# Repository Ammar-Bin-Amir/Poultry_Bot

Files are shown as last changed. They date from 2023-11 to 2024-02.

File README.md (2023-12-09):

# Poultry Bot

Poultry Bot is a major technological breakthrough for the poultry industry as it provides solution for utmost problems faced in a poultry farm. The purpose of poultry bot is to completely revolutionize the century old farming practices used till now by introducing the latest technology for 1,190 billion rupees turnover generating sector. The goal is to minimize the biosecurity risk to help improve the production. Further, assisting human to make more informed and better decisions. Poultry bot is an autonomous self-driven robot, monitoring several factors effecting on a poultry farm by implementing ROS and IoT along with LIDAR mapping.

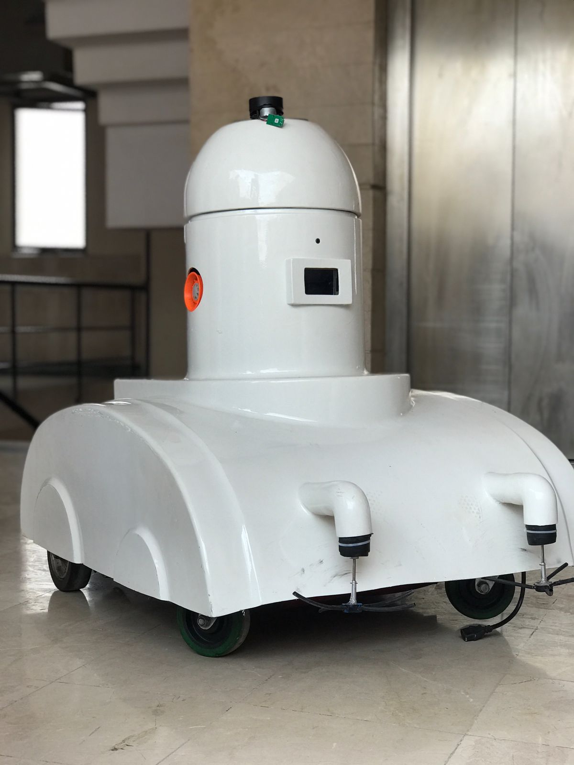
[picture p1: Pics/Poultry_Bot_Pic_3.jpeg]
Snapshot of Poultry Bot


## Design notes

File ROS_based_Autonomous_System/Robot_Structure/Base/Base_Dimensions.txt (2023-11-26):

4.5' Length
2.5' Width
2' Height
6" Ground Clearance
4.5" Length of Rod for Wheel Attachment
3.5" Location of Hole in Rod for Wheel Attachment

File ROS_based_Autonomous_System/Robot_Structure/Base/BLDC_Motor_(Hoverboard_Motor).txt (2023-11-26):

BLDC Motor (Hoverboard Motor)
*******************************
https://www.parallax.com/product/6-5-hub-motor-with-encoder/

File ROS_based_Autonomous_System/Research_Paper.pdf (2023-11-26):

1

# Poultry Bot: Autonomous Movement

Syed Sohaib Shere, Zain Ali, Muhammad Farhan Ur Rehman Malik, and Syed Musab Ullah Hussaini

Abstract—Poultry Bot is a major technological breakthrough
for the poultry industry as it provides solution for utmost problems faced in a poultry farm. The purpose of poultry bot is to completely revolutionize the century old farming practices used till now by introducing the latest technology for 1,190 billion rupees turnover generating sector. [1] The goal is to minimize the biosecurity risk to help improve the production. Further, assisting human to make more informed and better decisions. Poultry bot is an autonomous self-driven robot, monitoring several factors effecting on a poultry farm by implementing ROS and IoT along with LIDAR mapping.

Index Terms—Major Technical Breakthrough, ROS based Autonomous Self-Driven Robot, IoT Monitoring, LIDAR Mapping

I. INTRODUCTION

Poultry as a farming activity already existed for ages, over the 20th century, it became a real profession. In that century, poultry farming underwent several major revolutions in which the production system was drastically changed. In today’s poultry farming a significant part of the daily animal care is mechanized or automated like manure removal, climate control, automated medication, and litter racking. As these tasks contained limited complexity and variation, that are fulfilled using stepper motors and simple control logic. The properly running poultry shed still requires good stockman ship with intensive monitoring and awareness of animal of behavior and interactions as well as proper management and conscientiously performing of the daily task. This poultry bot comprises of implementation of IoT for monitoring important factors such as temperature, humidity, and air quality that can easily be detected by electronic discrete sensors that are particularly developed for single dedicated task. Another, innovative feature that is integrated with this robot is its autonomous movement which is to be done using a minicomputer which is specifically used to make this bot unique, efficient, and remarkable. Along with this, the technology of LIDAR is adopted to make the bot move precisely in the field area. Pesticide, that cannot be ignored when it comes to poultry care, is also integrated that will follow the defined scheduled spraying with controlled concentration according to the requirements of the shed.

II. PROBLEM STATEMENT

There are almost 15000 poultry farms in Pakistan despite of having such a huge industry not a single poultry robot is present due to restrictions on self-import, uneconomical cost, and lack of after sales services. [1]

By notifying real-time alerts and being cost-effective by lowering operational costs. Poultry Bot will enable the farmer to enhance productivity while eliminating the need for physical vigilance. The goal of poultry bot is to fully automate the process of monitoring and maintaining a poultry farm by providing tech-based solution for daily faced problems.

III. LITERATURE REVIEW

As for the poultry robots available worldwide, different robots are introduced with capabilities of various problem solving. Some of the available poultry robots are discussed as follows:

A. Poultry Patrol
By using thermal imaging, it enables the robot to detect disease and fatalities. The movement of birds is monitored to analyze their health. [2]
B. Octopus Robots
The bots continuously measure environmental factors, such as temperatures, humidity, carbon dioxide and ammonia levels, alerting farmers in real-time of deviations and potential problems. [3]
C. Robot Egg Collector
Poultry farms that give chickens open space to move around face the problem of random eggs laying all over the farm. The robotic egg collectors use an array of sensors to find and collect eggs without disturbing the chickens. [4]
D. Poultry Safe
It is capable of dealing with all types of substrates, turning and ventilating litter to prevent the exertion of ammonia gas and other diseases. [5]

IV. AIMS AND OBJECTIVES

The aims and objectives of this project is:

- To optimize the working time.
- To improve animal welfare.
- To increase the ADGs (average daily gain).
- To increase food security.
- To improve litter racking quality.
- To minimize the workforce.
- To reduce the human interaction.
- To make the project cost efficient.

2

V. FEATURES

The following features are included in this project:

1) LIDAR
a) Mapping
b) Localization
c) Navigation
2) Driving System
a) Remote Control
b) Autonomous Movement
3) Power Supply Unit
4) Litter Raking

VI. INDUSTRIAL APPLICATIONS

Poultry bot allows a poultry farm to improve the quality of poultry by improving animal well-being. This poultry bot will match the parallelism with the industrial revolutionary era 4.0 which is IoT based implementation in the industrial field. In addition to that, robotics technology in the form of ROS has been used that made the poultry bot move autonomously inside the poultry farm which will increase the efficiency and productivity. A major issue of lack in supervision of the animals that includes pest control, human concentration and inaccurate environmental factors monitoring would be countered by this single poultry bot that will boost the monthly revenue. Last but not the least, this bot would be cost efficient as it will minimize the monthly expenditures.

VII. HARDWARE DETAILS

The hardware details are as follows:

1) Mini PC
2) Arduino Mega 2560
3) BMS HX-3S-FL25A-A
4) 12V 1000W Inverter
5) Buck Converter XL-4016
6) Battery Pack Li-Ion 3S4P
7) Bluetooth Module HC-05
8) Two Channel Relay Module
9) Incremental Rotary Encoder
10) Battery Level Indicator MH-DL 18S
11) IBT2 H-Bridge Motor Driver Module
12) DC Geared Motors DGO-7024SIA
13) DC 12V 100W 775 High Speed Long Shaft Motor
14) RP Lidar A1M8 360 Degree Laser Scanner Development Kit

VIII. SOFTWARE DETAILS

The software details are as follows:

1) RViz
2) Linux
3) Gazebo
4) AutoCAD
5) Adobe Illustrator
6) Arduino Software
7) ROS (Robot Operating System)

IX. TENTATIVE OUTPUT

A poultry bot performs an inspection on the chicks in the shed, from litter racking to temperature monitoring, to assist the farmer in caring for their flock. Implementing this technology, will improve the quality of poultry and aid in achieving better results. The self-driving and self-controlling robot will reduce reliance on humans, resulting in increased production.

X. FUTURE WORK
- This project can be further improved by embracing AI and data-driven systems and enhancing disease control measures.
- Embrace AI and Data-Driven Systems: Emphasize the integration of highly adaptive artificial intelligence and data-driven systems in broiler and breeder production. These technologies can optimize operations, improve decision-making, and enhance overall efficiency.
- Enhance Disease Control Measures: Develop advanced disease detection and prevention strategies using AIdriven systems. Implement real-time monitoring and early warning systems to identify and control.

XI. REFERENCES

[1] “AN OVERVIEW OF PAKISTAN POULTRY INDUSTRY YEAR 2020-2021 – Pakistan Poultry Association.” https://pakistanpoultryassociation.com.pk/news/an-overview-of-pakistanpoultryindustry-year-2019-2020/ (accessed Jun. 20, 2022).
[2] “Autonomous robotics for the poultry shed | The Poultry Site.”
https://www.thepoultrysite.com/articles/autonomous-robotics-for-the-poultryshed (accessed Jun. 20, 2022).
[3] “Robots: the new frontier in poultry production | The Poultry Site.”
https://www.thepoultrysite.com/articles/robots-the-new-frontier-in-poultryproduction (accessed Jun. 20, 2022).
[4] “Best New Poultry Farm Equipment – 7 Robot & Automation Products.” https://agsolarsolutions.com/best-new-poultry-farm-equipment-2019/ (accessed Jun. 20, 2022).
[5] “Poultry Technology: Rise of the robots - Canadian Poultry MagazineCanadian Poultry Magazine.” https://www.canadianpoultrymag.com/rise-of-the-robots-30876/ (accessed Jun. 20, 2022).

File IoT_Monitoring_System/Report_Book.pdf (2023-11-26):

ST-13, Block 7, Gulshan-e-Iqbal, Abul Hasan Isphahani Road, Opposite Safari Park, P.O. Box 75300, Karachi, Pakistan. Phone: 34978274-5; 34994305; 34982476; http://www.uit.edu

# USMAN INSTITUTE OF TECHNOLOGY

### Affiliated with NED University of Engineering & Technology, Karachi

## Department of Electrical Engineering

## B.E. Electrical (Electronics Engineering)

## FINAL YEAR PROJECT REPORT

## Batch-2019

## POULTRY BOT: MONITORING SYSTEM

By

Ammar Bin Amir | 19B-004-EE
Maaz Siddiqui | 19B-008-EE
Osama Bin Khalid Raza | 17B-051-EE
Muhammad Qasim Umer Qureshi | 19B-062-CE

Supervised by

### Dr. Abid Karim (Professor)

Poultry Bot: Monitoring System

I

DECLARATION

I hereby declare that this project report is based on my original work except

for citations and quotations which have been duly acknowledged. I also declare that

it has not been previously and concurrently submitted for any other degree or award

at USMAN INSTITUTE OF TECHNOLOGY or other institutions.

Student Name (Student ID): Ammar Bin Amir (19B-004-EE)

Signature: _________________________

Student Name (Student ID): Maaz Siddiqui (19B-008-EE)

Signature: _________________________

Student Name (Student ID): Osama Bin Khalid Raza (17B-051-EE)

Signature: _________________________

Student Name (Student ID): Muhammad Qasim Umer Qureshi (19B-062-CE)

Signature: _________________________

Date: _________________________

II

ACKNOWLEDGEMENT

Alhamdulillah, praise to Allah the almighty for His blessings and for

allowing us to complete this study and completion of the Poultry Bot project in the

given time to whom we would like to express our highest gratitude.

Then, we would like to thank my Final Year Project Supervisor, Dr. Abid

Karim, for his continuous support and guidance. He had not only given essential

theories and ideas for completing this project but also informally guided us in

developing our values to make us better people.

The sponsorship provided by the alumnus of UIT, Engr. Athar Alam has

enabled us to access essential resources, materials, and equipment necessary for the

successful execution of our project. His belief in the potential of our endeavor has

motivated us throughout this journey, and we are immensely grateful for his trust in

our abilities.

We would also like to express our great appreciation to our Sponsor and

donor of Mohammad Younus Khan Award of Rs.50,000 (rupees fifty thousand only)

for final year projects (FYPs) groups working in the area of Electric Vehicles (EVs).

Our earnest appreciation to Engr. Muhammad Timur for all his guidance and

assistance in helping us throughout the time of the project period. His guidance and

expert insights have been crucial in shaping the direction of our project. His

experience has provided us with valuable perspectives, helping us to refine our ideas

and develop innovative solutions.

Finally, an honorable mention goes to our families, especially our parents,

who have always prayed for our success and given their utmost moral support in our

life. We hope we can always be there for them in the way they supported us.

III

POULTRY BOT: MONITORING SYSTEM

ABSTRACT

Poultry Bot is a major technological breakthrough for the poultry industry as

it provides solutions for the utmost problems faced in a poultry farm. The purpose of

the poultry bot is to completely revolutionize the century-old farming practices used

till now by introducing the latest technology for the 1,190 billion rupees turnover

generating sector. The goal is to minimize the biosecurity risk to help improve

production. Furthermore, assisting humans to make more informed and better

decisions. The poultry bot is an autonomous self-driven robot that performs all the

required operations in the poultry farm which includes monitoring, patrolling, litter-

racking, and disinfectant spraying. Overall, the Poultry Bot's introduction to the

poultry industry heralds a transformative era, promising higher levels of biosecurity,

production enhancement, and informed decision-making.

IV

TABLE OF CONTENTS

DECLARATION | I
ACKNOWLEDGEMENT | II
ABSTRACT | III
TABLE OF CONTENTS | IV
LIST OF FIGURES | VII
LIST OF TABLES | VIII
PROGRAM LEARNING OUTCOMES (PLOS) MAPPING | IX

V

VI

VII

LIST OF FIGURES

FIGURE 2.22 ARDUINO IDE (INTEGRATED DEVELOPMENT ENVIRONMENT) SOFTWARE

FIGURE 3.2 COMPLETE CIRCUIT OF PROCESSING UNIT INTEGRATED ON THE

FIGURE 3.3 INDICATION OF POWER SUPPLY UNIT CONTROLLED THROUGH SWITCH ALONG WITH BATTERY LEVEL INDICATOR INDICATING 75% CHARGING

FIGURE 4.1 IMAGE OF ROBOT STRUCTURE DISPLAYING NEXTION HMI LCD, CAMERA MODULE, AND TWO SPRAY NOZZLES (IN ORANGE COLOR) ON LEFT AND RIGHT 49 FIGURE 4.2 IMAGE OF NEXTION HMI LCD (BOTTOM) AND CAMERA MODULE (TOP)

VIII

LIST OF TABLES

IX

PROGRAM LEARNING OUTCOMES (PLOs) MAPPING

Chapters 1 through 4 and Appendix

PLO-(x)-Communication

PLO-(viii)-Ethics

PLO-(ix)-Individual & Teamwork

Chapter 01-Introduction | PLO-(ii)-Problem Analysis
Chapter 02-Methodology | PLO-(iv)-Investigation

Chapter 03-Implementation

PLO-(iii)-Design/Development of Solution

PLO-(v)-Modern Tool Usage

# CHAPTER # 01

# INTRODUCTION

## 1. Introduction

Poultry as a farming activity already existed for ages, over the 20th century, it

became a real profession. In that century, poultry farming underwent several major

revolutions in which the production system was drastically changed. In today’s

poultry farming a significant part of the daily animal care is mechanized or

automated like manure removal, climate control, automated medication, and litter

raking. As these tasks contain limited complexity and variation, they are fulfilled

using motors and simple control logic. The properly running poultry shed still

requires good stockmanship with intensive monitoring and awareness of animal

behavior and interactions as well as proper management and conscientious

performing of the daily task. This poultry bot comprises of implementation of IoT for

monitoring important factors such as temperature, humidity, and air quality that can

easily be detected by electronic discrete sensors that are particularly developed for a

single dedicated task. Another, innovative feature that is integrated with this robot is

its autonomous movement which is to be done using a minicomputer which is

specifically used to make this bot unique, efficient, and remarkable along with the

technology of LIDAR which is adopted to make the bot move precisely in the field

area. Disinfectant and anti-bacterial, which cannot be ignored when it comes to

poultry care, are also integrated that will follow the user-defined scheduled spraying

with controlled concentration according to the requirements of the shed.

### 1.1. Problem Statement

The poultry industry faces various challenges related to efficiency,

productivity, and animal welfare. However, the major challenge facing poultry

farming is reconciled productivity, biosecurity, and expectations of society where the environment and animal welfare are of major concern. To address

these challenges, the development of a poultry robot is proposed. The objective

of the poultry robot is to automate and optimize various tasks involved in

poultry farming and management.

There are almost 15000 poultry farms in Pakistan despite having such a

huge industry not a single poultry robot is present due to restrictions on self-

import, uneconomical cost, and lack of after-sales services[1]
. Poultry Bot will

enable the farmer to enhance productivity while eliminating the need for

physical vigilance. The goal of the poultry bot is to fully automate the process

of monitoring and maintaining a poultry farm by providing tech-based

solutions for daily faced problems.

By deploying poultry robots, farmers can significantly reduce the labor

costs associated with poultry farming while maintaining high standards of

animal welfare. The robot's ability to work continuously ensures round-the-

clock monitoring and care for the birds, leading to better overall farm

management. Moreover, the data collected by the robot's sensors can be

analyzed to gain valuable insights into the birds' health, behavior patterns, and

productivity, enabling farmers to make data-driven decisions and optimize

their operations further.

### 1.2. Literature Review

As for the poultry robots available worldwide, different robots are

introduced with capabilities of various problem-solving. Some of the available

poultry robots are discussed as follows:

### 1.2.1. Poultry Patrol

By using thermal imaging, it enables the robot to detect disease

and fatalities. The movement of birds is monitored to analyze their

health[2]

Figure 1.1 Poultry Patrol

### 1.2.2. Octopus Robot

The bots continuously measure environmental factors, such as

temperatures, humidity, carbon dioxide, and ammonia levels, alerting

farmers in real time of deviations and potential problems[3]

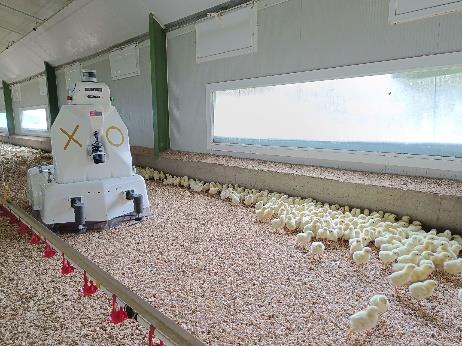
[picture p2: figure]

Figure 1.2 Octopus Robot

### 1.2.3. Robot Egg Collector

Poultry farms that give chickens open space to move around face

the problem of random eggs laying all over the farm. The robotic egg

collectors use an array of sensors to find and collect eggs without

disturbing the chickens[4]

Figure 1.3 Robot Egg Collector

### 1.2.4. Poultry Safe

It is capable of dealing with all types of substrates, turning and

ventilating litter to prevent the exertion of ammonia gas and other

diseases.

All the robots mentioned above are catering to a certain problem

but there are certain limitations and challenges associated with poultry

robots, including technological constraints, cost considerations, and

integration with existing farm systems. However, poultry bot minimizes

these problems[5]

Figure 1.4 Poultry Safe

### 1.3. Aims and Objectives

The Poultry Bot aims to enhance daily poultry farm production

conditions with advanced technologies focused on health, biosecurity, and

productivity. Objectives include improving poultry quality by enhancing animal well-being and minimizing antibiotic use, sanitizing bedding to control

multi-resistant bacteria and infectious diseases while reducing ammonia levels,

and uniformly decontaminating buildings during fallow periods. Additionally,

the Poultry Bot aims to increase yields through improved animal weight and

reduced interim costs, promoting more efficient and sustainable poultry

farming practices.

### 1.3.1. To Optimize the Working Time

The Poultry Bot aims to streamline and optimize the working

time in poultry farming operations by employing its autonomous and

connected features. The robot can efficiently perform tasks that would

otherwise require significant manual labor and time. The Poultry Bot can

complete essential functions such as decontamination, sanitization, and

monitoring without the need for constant human supervision. This

optimization of working time allows poultry farmers to focus on other

critical aspects of their operations, leading to increased productivity and

improved overall efficiency.

### 1.3.2. To Improve Animal Welfare

The robot's atomization technology allows the decontamination

and sanitization of the poultry farm environment, creating a healthier and

cleaner living space for the birds. By minimizing the presence of harmful

bacteria, infectious agents, and ammonia concentrations in the bedding,

the Poultry Bot promotes better health and comfort for the birds.

### 1.3.3. To Increase the ADGs (Average Daily Gain)

The Poultry Bot plays a crucial role in boosting the average daily

gain (ADG) of poultry. By maintaining a clean and hygienic

environment, the robot reduces stress factors that can hinder the growth

and development of the birds. The optimized living conditions provided

by the Poultry Bot contribute to improved feed conversion rates and

nutrient absorption, leading to higher ADGs.

### 1.3.4. To Improve Litter Raking Quality

The Poultry Bot's technology for regularly cleaning and removing

soiled litter ensures a high-quality decontamination process, including

the sanitization of the bedding. By effectively reducing the concentration

of multi-resistant bacteria and ammonia, the robot helps maintain cleaner

and healthier litter-raking conditions. Improved litter quality not only

benefits animal health and welfare but also facilitates easier waste

management for poultry farmers, leading to more sustainable and eco-

friendly practices.

### 1.3.5. To Minimize the Workforce

With its autonomous and connected features, the Poultry Bot

minimizes the need for a large workforce in poultry farming operations.

Once deployed, the robot can carry out its tasks independently, reducing

the labor-intensive aspects of manual cleaning and decontamination. This

cost-effective solution allows farmers to optimize labor resources,

allocate manpower to more strategic tasks, and potentially reduce

operational expenses.

# CHAPTER # 02

# METHODOLOGY

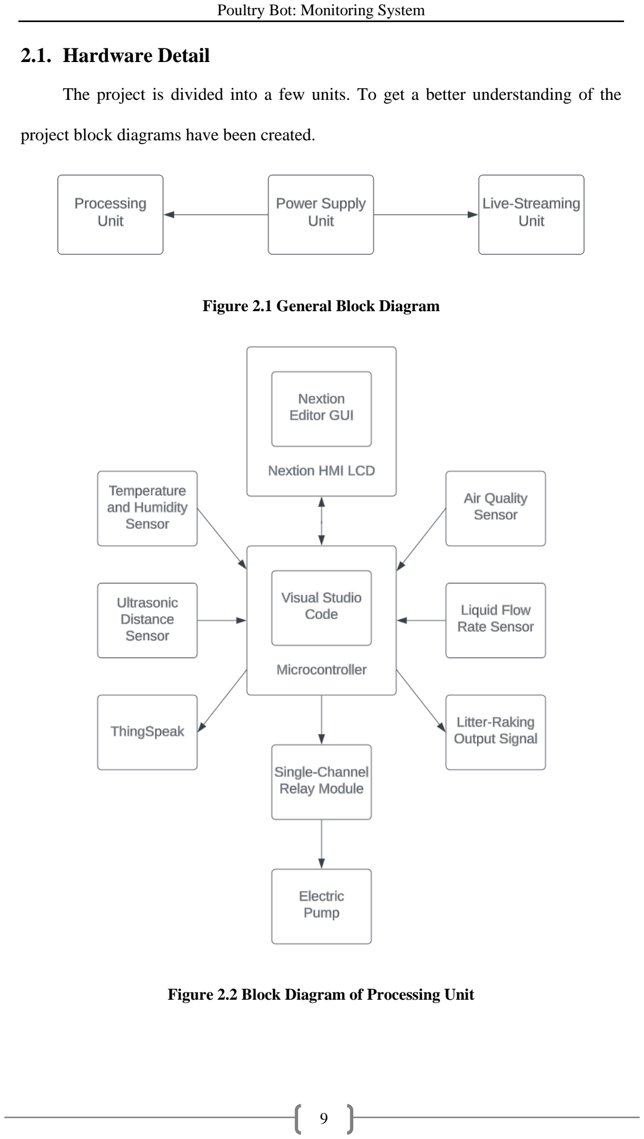
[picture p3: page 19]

### 2.1. Hardware Detail

The project is divided into a few units. To get a better understanding of the

project block diagrams have been created.

Figure 2.1 General Block Diagram

Figure 2.2 Block Diagram of Processing Unit

Figure 2.3 Block Diagram of Power Supply Unit

Figure 2.4 Block Diagram of Live-Streaming Unit

The hardware used in this project is mentioned in detail as follows:

### 2.1.1. Microntroller

A microcontroller is a compact integrated circuit that contains a

processor core, memory, and peripherals, designed for embedded systems and

control applications. It serves as the brain of small-scale devices, managing

their operations and executing tasks based on pre-programmed instructions.

ESP32 DevKit Module is used as a microcontroller in this project.

The ESP32 DevKit module is a versatile and powerful development

board based on the ESP32 microcontroller. It features a dual-core 32-bit

processor running at up to 240 MHz, equipped with Wi-Fi and Bluetooth

connectivity, making it ideal for Internet of Things (IoT) projects. The module

offers a wide range of peripherals, including GPIO pins, UART, SPI, I2C,

ADC, and PWM, providing flexibility for various applications. With ample

memory resources and built-in security features, it enables the efficient

development of connected devices and applications. Its compact form factor,

cost-effectiveness, and extensive software support through the Espressif IoT

Development Framework (ESP-IDF) and Arduino IDE make the ESP32

DevKit a popular choice for IoT prototyping and development. The ESP32

DevKit module operates at a voltage range of typically 3.3V to 3.6V, making it

compatible with various power supply sources. In terms of current

specifications, the ESP32 DevKit module typically consumes around 80mA to

260mA during normal operation, depending on the tasks and functionalities

enabled.

Figure 2.5 Microcontroller: ESP32 Devkit Module

### 2.1.2. Temperature and Humidity Sensor

Temperature is a measure of the average kinetic energy of the particles

in a substance. It determines the hotness or coldness of an object and is

measured using the Celsius, Fahrenheit, or Kelvin scale.

Humidity is a measure of the amount of water vapor present in the air.

It indicates how saturated the air is with water vapor at a specific temperature.

The DHT22 is a digital temperature and humidity sensor designed to

accurately measure ambient temperature and relative humidity in a wide range

of applications. It features a single-wire communication interface, making it

easy to integrate with microcontrollers and other devices. The sensor boasts a

temperature measurement range of -40°C to 80°C with an accuracy of ±0.5°C and a humidity measurement range of 0% to 100% with an accuracy of ±2%.

Its low power consumption and quick response time make it suitable for

various projects such as weather monitoring systems, home automation, and

industrial applications where reliable temperature and humidity data are

essential. The DHT22 temperature and humidity sensor operates within a

voltage range of 3.3V to 5.5V, making it compatible with most

microcontrollers and embedded systems. When powered, the DHT22

consumes an average current of around 2.5mA during normal operation.

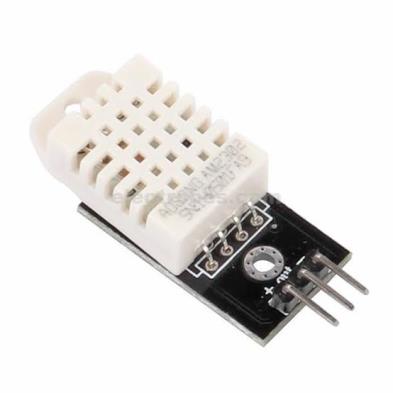
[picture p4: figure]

Figure 2.6 Temperature and Humidity Sensor: DHT22

### 2.1.3. Air Quality Sensor

Air quality refers to the cleanliness and healthiness of the air we

breathe, determined by the concentration of pollutants and particulate matter in

the atmosphere, which can impact human health and the environment. Factors

such as emissions from vehicles, industrial activities, and natural sources

contribute to air quality levels.

The MQ135 is a gas sensor module used to detect a wide range of

harmful gases in the atmosphere, including ammonia, nitrogen oxides,

benzene, and other volatile organic compounds. It operates on the principle of

chemiresistance, where the resistance of the sensing material changes when it comes into contact with specific gases, thus allowing the sensor to measure gas

concentrations. The MQ135 is commonly utilized in various applications, such

as air quality monitoring devices, indoor air quality assessments, and gas leak

detection systems, due to its sensitivity and cost-effectiveness, making it a

popular choice for environmental monitoring and safety purposes. It typically

operates at a voltage of 5V DC and consumes a low current, usually around

150mA, making it suitable for use with microcontrollers like Arduino and

ESP32.

Figure 2.7 Air Quality Sensor: MQ135

### 2.1.4. Ultrasonic Distance Sensor

Ultrasonic distance refers to measuring the distance to an object by

emitting high-frequency sound waves and calculating the time it takes for the

waves to bounce back after hitting the object.

The HC-SR04 is an ultrasonic sensor module widely used for distance

measurement in various applications. It operates by emitting ultrasonic sound

waves and measuring the time it takes for the waves to bounce back after

hitting an object. The module consists of two main components: a transmitter

and a receiver. The transmitter sends out ultrasonic pulses, and the receiver

detects the echoes. By calculating the time difference between sending and receiving signals and knowing the speed of sound in the air, the module can

determine the distance to the object. It typically has a measurement range of

2cm to 400cm and features four pins: VCC for power supply (5V), GND for

ground connection, TRIG for trigger signal input, and ECHO for echo signal

output. This simple yet effective design makes the HC-SR04 popular for

distance sensing in robotics, automation, and other projects. The HC-SR04

ultrasonic sensor operates at a voltage range of 5V DC, making it compatible

with most microcontrollers and Arduino boards. The sensor's operating current

typically ranges from 2mA to 15mA during active mode, depending on the

duration and frequency of measurements.

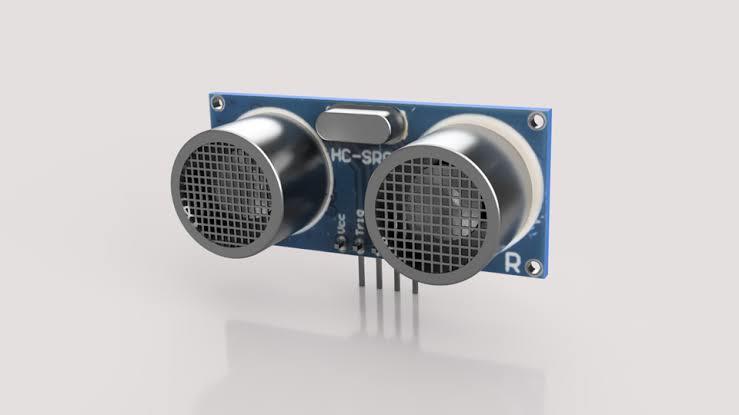
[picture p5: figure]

Figure 2.8 Ultrasonic Distance Sensor: HC-SR04

### 2.1.5. Liquid Flow Rate Sensor

Liquid flow rate refers to the volume of liquid passing through a point

per unit of time, typically measured in liters per minute or gallons per hour.

The YF-S201 is a liquid flow sensor module widely used in various

applications to measure the flow rate of liquids. Its specification includes a

compact design, featuring a small and lightweight body for easy integration

into different systems. The sensor utilizes a hall effect sensor to detect the flow

of liquids, making it highly reliable and accurate. It operates within a wide flow rate range, typically from 0.3 to 6 liters per minute, and is compatible

with various liquids, including water and other non-corrosive liquids. The YF-

S201 is equipped with a pulse output that provides a frequency signal

corresponding to the flow rate, making it convenient for interfacing with

microcontrollers and other electronic devices. The voltage specifications for

the YF-S201 typically range from 5V to 24V DC, making it compatible with

various microcontrollers and systems. The YF-S201 water flow sensor has a

low current consumption, typically in the range of a few milliamperes during

operation, having a maximum working current of up to 15mA.

Figure 2.9 Liquid Flow Rate Sensor: YF-S201

### 2.1.6. Single-Channel Relay Module

A relay is an electrically operated switch that uses an electromagnet to

control the flow of current in a circuit. It allows low-power signals to control

higher power loads, making it essential in various electronic and electrical

applications.

The single-channel relay module is designed to control high-voltage

electrical devices through a low-voltage microcontroller or other control

systems. It features a high-quality relay capable of handling up to a specified

maximum current and voltage rating. The module typically operates at a specific input voltage, and its input control signal is triggered by either a low or

high voltage, activating or deactivating the relay accordingly. It is equipped

with screw terminals for easy connection of external devices and has an LED

indicator to show the relay's status. This versatile and compact module is

commonly used in various automation, robotics, and home automation projects

where the control of high-power devices is required. The relay module

typically operates with a coil voltage of 5V or 12V, depending on the specific

variant. The maximum switching voltage can range from 110V to 250V AC or

up to 30V DC, and the maximum switching current varies between 10A to

30A.

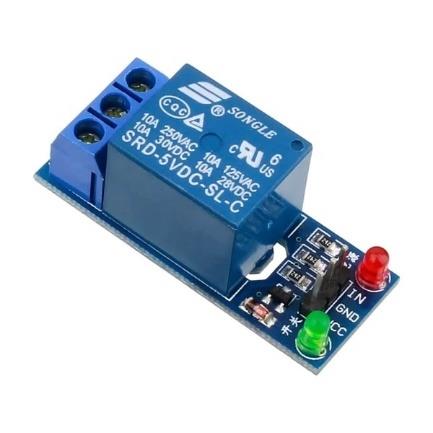
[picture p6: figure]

Figure 2.10 Single-Channel Relay Module: HW-307B

### 2.1.7. Electric Pump

An electric pump is a device that uses electrical energy to create

mechanical motion, enabling the transfer of fluids such as water or air. It

operates by converting electrical power into kinetic energy, generating flow or

pressure within the fluid system.

The device operates at a voltage of 12 volts with a nominal range of 9

to 14 volts, indicating that it can handle fluctuations within this range. The

device draws a current of 3.5 amps, which represents the amount of electrical charge passing through it per unit of time. Additionally, the device has a flow

rate of 5.0 liters per minute (LPM), which refers to the volume of fluid it can

handle or transfer in a minute. Moreover, it can generate a pressure of 125

pounds per square inch (PSI) or 7.0 bar, signifying its ability to maintain or

sustain a specific pressure level.

Figure 2.11 12V DC Electric Pump

### 2.1.8. Structure of Spraying Unit

Spraying unit is basically the complete system where all the monitoring

and controlling is done related to liquid. It contains 19L water bottle, 8-hole

agricultural nozzle and 1 inch HDPE (High Density Polyethylene) water pipes

along with ultrasonic distance sensor and liquid flow rate sensor.

### 2.1.8.1. Liquid Storage Tank

A 19-liter spraying unit is a portable piece of equipment used for

spraying liquids in various applications. It consists of a 19-liter capacity

tank that can hold liquids such as water, pesticides, herbicides, or

fertilizers.

Figure 2.12 Liquid Storage Tank: 19 Liter Water Bottle

### 2.1.8.2. Water Pipe

A 1-inch HDPE water pipe is a durable and versatile pipe used for

transporting potable water in various applications. HDPE stands for high-

density polyethylene, a thermoplastic material known for its excellent

strength, flexibility, and resistance to corrosion and chemicals. HDPE

water pipes are lightweight, easy to handle, and can withstand harsh

environmental conditions, making them a reliable choice for long-term

water distribution systems.

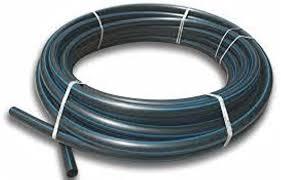
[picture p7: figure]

Figure 2.13 Water Pipe: 1 Inch HDPE Pipe

### 2.1.8.3. Spray Nozzle

An 8-hole agriculture spray nozzle is a specialized component used in

agricultural irrigation systems for the controlled dispersion of water or fertilizers onto crops. This nozzle features eight small holes or orifices

through which the liquid is released in the form of fine droplets. The

multi-hole design ensures uniform coverage across the crop area,

promoting even distribution of water and nutrients. By creating a mist-

like spray pattern, minimizes water wastage and optimizes the efficiency

of irrigation.

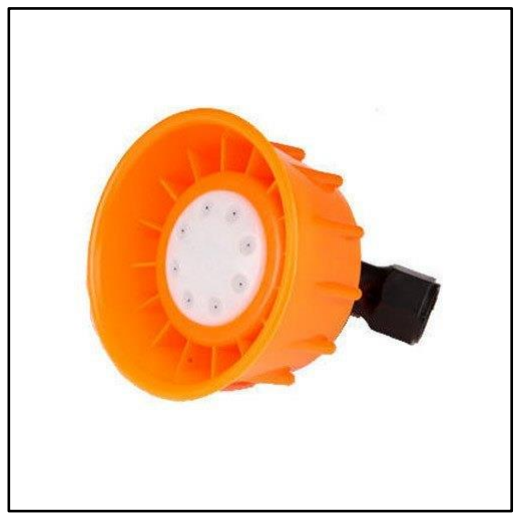
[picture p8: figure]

Figure 2.14 Spray Nozzle: 8-Hole Agricultural Spray Nozzle

### 2.1.9. Nextion HMI LCD

HMI LCD stands for Human-Machine Interface Liquid Crystal Display.

It is a type of display technology used to visually interact with and control

machines or systems through a user-friendly interface.

The HMI LCD NX4832T035 is a human-machine interface (HMI)

display module designed for industrial applications. It features a 3.5-inch TFT

LCD screen with a resolution of 480x320 pixels, providing clear and vibrant

visual output. The module is equipped with a resistive touchscreen for intuitive

user interaction, enabling precise input and control. The HMI supports multiple

communication protocols, facilitating seamless integration with various

industrial devices and systems. With a robust design and wide operating

temperature range, it ensures reliable performance in harsh environments. The

NX4832T035 is an efficient and user-friendly HMI solution, ideal for

enhancing human-machine interaction in industrial automation and control

processes. The module operates at a voltage range of 4.5V to 7V and consumes

a low current of up to 145mA and 15mA when in sleep mode.

Figure 2.15 Nextion HMI LCD: NX4832T035

### 2.1.10. Camera Module

A camera module is a compact imaging device integrated into

electronic devices, capturing visual information by converting light into

electronic signals for storage or display purposes.

The ESP32-CAM is a versatile and compact development module

featuring the ESP32-S chip, designed for implementing various Internet of

Things (IoT) and camera applications. It comes equipped with a high-

performance 32-bit dual-core processor running at up to 240MHz, integrated

Wi-Fi, and Bluetooth connectivity, which allows seamless communication with

other devices and the internet. The module incorporates an OV2640 camera

sensor capable of capturing images up to 2 megapixels and streaming video at

resolutions up to 1600x1200. Additionally, it supports various communication

interfaces like UART, I2C, SPI, and PWM, offering flexibility for connecting

external sensors and peripherals. The ESP32-CAM can be programmed and configured using Arduino IDE and its GPIO pins allow for easy integration

into different projects, making it an ideal choice for IoT applications, home

automation, surveillance systems, and more. It operates with a recommended

voltage supply of 5V and can handle a typical current consumption of around

800mA during peak operations, such as capturing images or streaming video.

Figure 2.16 Camera Module: ESP32-CAM

### 2.1.11. Printed Circuit Board (PCB)

PCB stands for "Printed Circuit Board," it is a flat board made of

insulating material with printed copper traces that connect electronic

components, enabling the assembly and functioning of electronic circuits.

A Printed Circuit Board (PCB) is a crucial component in modern

electronics, serving as a physical platform to support and connect various

electronic components. The PCB's specifications encompass several essential

aspects: its dimensions, number of layers, material composition (typically

fiberglass-reinforced epoxy), copper thickness, and trace width. Additionally,

the specification details the layout of components, vias, and interconnects,

ensuring proper signal flow and electrical integrity. The PCB's design may

include specific features such as surface mount technology (SMT) pads or

through-hole connections, depending on the application's requirements. The overall aim is to create an optimized, reliable, and efficient electrical pathway

that enables the seamless functioning of the electronic device it's integrated

into.

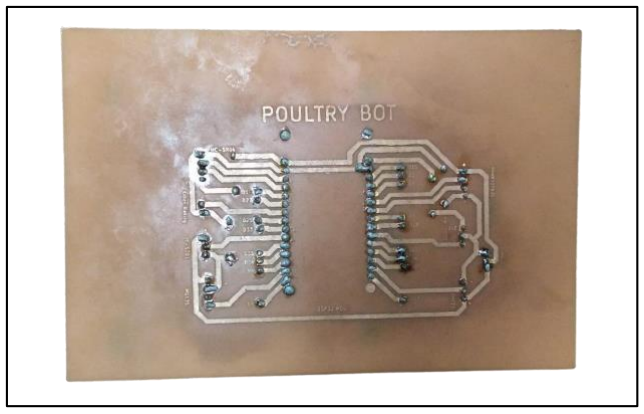
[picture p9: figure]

Figure 2.17 Printed Circuit Board (PCB)

### 2.1.12. Battery Pack

A battery pack is a collection of individual batteries connected to store

electrical energy efficiently and provide a portable power source for various

devices and applications. It allows for convenient recharging and discharging

of stored energy as needed.

The Li-ion 3S4P 12V battery pack features Murata VTC6A 21700

lithium-ion cells, where three of these high-performance cells are connected in

series to achieve a nominal voltage of 11.1 volts based on the individual cell's

capacity of approximately 3.7V. Additionally, four sets of these series-

connected cells are arranged in parallel to enhance the total capacity, providing

a combined capacity of, 16400mAh (or 16.4Ah) based on the individual cell's

capacity of approximately 41000mAh. The Murata VTC6A 21700 cells offer

excellent energy density and performance. The battery pack incorporates

essential safety features such as overcharge protection, over-discharge protection, and short-circuit protection, ensuring secure and reliable operation

for various applications.

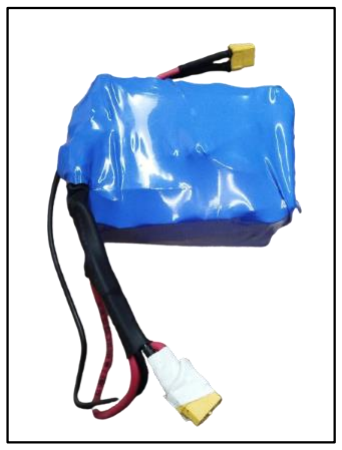
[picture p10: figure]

Figure 2.18 Battery Pack: Li-Ion 12V 3S4P

### 2.1.13. Battery Management System (BMS)

BMS stands for "Battery Management System." It is an electronic

control unit that monitors and optimizes the performance of rechargeable

batteries, ensuring their safe and efficient operation in various applications like

electric vehicles and renewable energy systems.

The HX-3S-FL25A-A is a lithium battery protection board designed for

3-series (3S) Li-ion battery packs. It provides essential protection features to

ensure the safe and efficient operation of the battery pack. The board supports

a maximum continuous discharge current of 25A, making it suitable for

various applications requiring high-power output. Equipped with overcharge,

over-discharge, overcurrent, and short-circuit protection, the HX-3S-FL25A-A

safeguards the battery cells against potential risks, extending their lifespan and

enhancing safety. Its compact design and easy integration make it an ideal

choice for DIY projects, robotics, electric vehicles, and other battery-powered

devices.

Figure 2.19 Battery Management System (BMS): HX-3S-FL25A-A

### 2.1.14. Buck Converter

A buck converter is a type of DC-DC power converter that steps down

voltage levels efficiently, providing a lower output voltage than the input by

controlling the switch's on-off cycles. It's commonly used to power electronic

devices with a stable, reduced voltage.

XL-4016 is a high-performance step-down buck converter integrated

circuit (IC) designed to efficiently regulate voltage levels in power supply

applications. Operating with a wide input voltage range, typically from 4V to

40V, it can deliver a continuous output current of up to 8A. The IC utilizes

pulse width modulation (PWM) technology to achieve a high conversion

efficiency, minimizing power losses and maximizing power conversion. Its

output voltage can be easily adjusted through an external resistor, making it

versatile for various electronic devices and projects. The XL-4016 features

built-in protection mechanisms such as overcurrent, over-temperature, and

short-circuit protection, ensuring safe and reliable operation in diverse

applications, including battery chargers, LED drivers, and embedded systems.

Figure 2.20 Buck Converter: XL4016

### 2.1.15. Battery Level Indicator

A battery level indicator shows the remaining charge of a battery,

typically displayed as a percentage or a visual representation of bars.

The MH-DL 18S battery level indicator is a device used to monitor and

display the charge status of a battery. The specification includes a compact and

user-friendly design, featuring a digital LED display that shows the battery's

remaining capacity in percentage or voltage units. It is equipped with intuitive

controls for easy operation and can be easily attached to the battery pack with a

secure mounting mechanism. Additionally, the MHDL 18s indicator offers

multiple levels of accuracy, providing precise and reliable information about

the battery's power level, helping users efficiently manage their power

resources, and ensure uninterrupted operation in various applications and

environments.

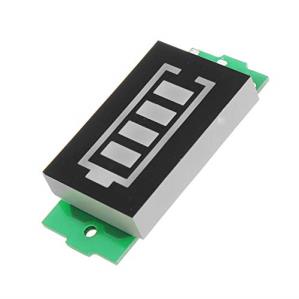
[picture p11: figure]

Figure 2.21 Battery Level Indicator: MH-DL 18S

### 2.2. Software Detail

The software used in this project are as follows:

### 2.2.1. Arduino Software

The Arduino Integrated Development Environment (IDE) is a user-

friendly, cross-platform software tool used for programming and developing

applications on Arduino microcontroller boards. It provides a simplified

interface for writing, compiling, and uploading code to Arduino boards,

making it accessible to both beginners and experienced developers. The IDE

supports the C/C++ programming language and comes with a vast library of

pre-written functions, simplifying the process of creating interactive projects

with sensors, motors, and other hardware components. Additionally, it offers

a Serial Monitor for debugging and monitoring data from the Arduino board,

along with a range of useful tools for code analysis and project management.

Overall, the Arduino IDE serves as an essential and versatile platform for

unleashing creativity and innovation in the world of electronics and

embedded systems.

Figure 2.22 Arduino IDE (Integrated Development Environment) Software

### 2.2.2. ThingSpeak

ThingSpeak is an internet of things (IoT) platform that enables users

to collect, analyze, and visualize data from connected devices and sensors. It

serves as a cloud-based data storage and processing system that allows developers and enthusiasts to easily capture real-time data, store it in

channels, and access it through APIs. With its user-friendly interface,

ThingSpeak offers various features such as data logging, data visualization,

and the ability to trigger actions based on predefined conditions. Users can

monitor and interact with their IoT devices remotely, making it an ideal

solution for building smart applications and monitoring systems for a wide

range of applications, including agriculture, home automation, industrial

monitoring, and more.

Figure 2.23 ThingSpeak Software

### 2.2.3. Nextion Editor

The Nextion Editor is a powerful software tool used to design and

develop graphical user interfaces (GUIs) for Nextion series intelligent display

modules. It offers a user-friendly WYSIWYG (What You See Is What You

Get) interface that allows designers and developers to create visually

appealing touch-screen interfaces without the need for complex coding. The

editor supports drag-and-drop functionality, making it easy to add buttons,

text, images, and other interactive elements. With various pre-built

components and customization options, designers can quickly prototype and

implement their GUI designs. Additionally, the Nextion Editor enables

seamless integration with microcontrollers, enabling efficient communication

and control between the display and the external device. Overall, the Nextion

Editor streamlines the GUI development process, making it accessible for

both beginners and experienced developers.

Figure 2.24 Nextion Editor Software

### 2.2.4. Visual Studio Code

Visual Studio Code (VS Code) is a highly popular, free, and

lightweight integrated development environment (IDE) developed by

Microsoft. It is designed to provide a versatile coding experience for

developers across various platforms, including Windows, macOS, and Linux.

With an extensive ecosystem of extensions, VS Code supports numerous

programming languages and frameworks, making it adaptable to different

development workflows. The editor offers an intuitive user interface,

powerful code editing features like IntelliSense, code refactoring, and Git

integration, facilitating seamless collaboration and version control. Its

customizable layout, built-in terminal, and integrated debugging capabilities

enhance productivity and streamline the development process. Combining

performance, flexibility, and community-driven support, Visual Studio Code

is an excellent choice for modern software development tasks.

Figure 2.25 Visual Studio Code Software

### 2.2.5. Ki-CAD

KiCad is an open-source Electronic Design Automation (EDA)

software suite that facilitates the creation of schematics and printed circuit

boards (PCBs). It offers a comprehensive set of tools, including schematic

capture, PCB layout, and component footprint libraries, allowing engineers

and hobbyists to design complex electronic circuits. KiCad supports various

file formats, making it compatible with different industry standards, and it is

available for Windows, macOS, and Linux operating systems. Its user-

friendly interface, extensive community support, and continuous development

make KiCad a popular choice for electronics enthusiasts seeking an

accessible yet powerful solution for their PCB design needs.

Figure 2.26 Ki-CAD Software

### 2.2.6. MIT App Inventor

MIT App Inventor is a user-friendly and intuitive web-based platform

developed by the Massachusetts Institute of Technology (MIT) that enables

individuals, particularly those with little to no prior programming experience,

to create mobile applications for Android devices. The platform utilizes a

visual programming approach, allowing users to design apps by simply

dragging and dropping components and blocks of code to define their

functionality. It abstracts the complexities of traditional programming

languages and empowers users to build interactive and functional apps through a simplified interface. By providing a vast array of pre-built

components and integration with device sensors and functionalities, MIT App

Inventor allows for rapid app development and fosters creativity among

aspiring app creators, making it an excellent tool for educational and hobbyist

purposes.

Figure 2.27 MIT App Inventor

# CHAPTER # 03

# PROJECT IMPLEMENTAION

### 3.1. Details of Hardware Implementation

The project is divided into a few units. To get a better understanding of the

project implementation, a schematic has been given below.

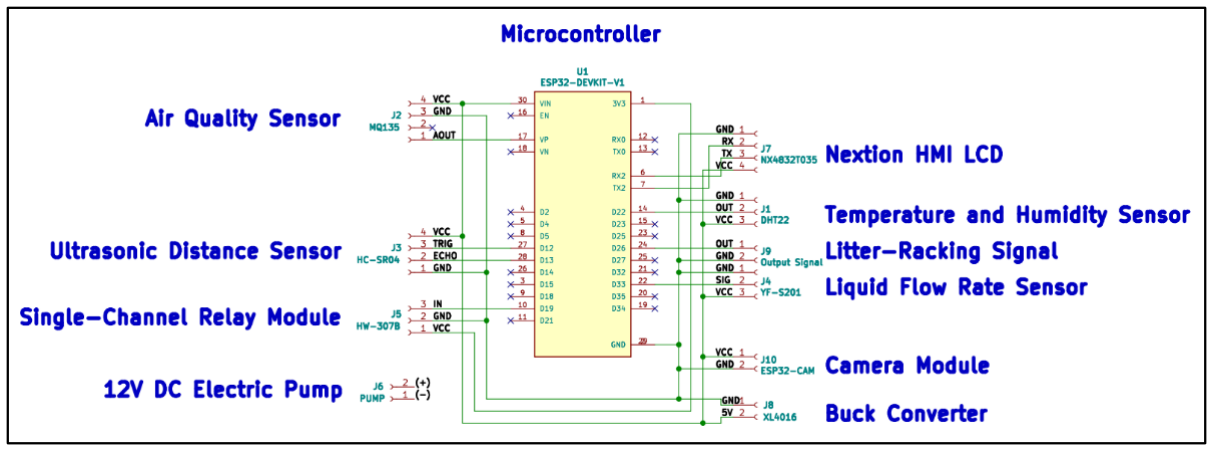
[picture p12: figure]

Figure 3.1 Circuit’s Schematic Diagram

### 3.1.1. Processing Unit

The components used in the processing unit are ESP32 Devkit Module,

DHT22, MQ135, HC-SR04, YF-S201, HW-307B, Electric Pump, and

NX4832T035 in addition to an output pin for litter-raking.

### 3.1.1.1. Connections in Processing Unit

The DHT22 sensor has three pins; VCC, GND, and OUT pin

(digital pin for communication). The VCC and GND pins are given 5V

and GND from the power supply whereas the data pin is connected to the

GPIO pin of ESP32 which is D22.

The MQ135 sensor has four pins; VCC, GND, AOUT (analog

output), and DOUT (digital output). The VCC and GND are connected to

the 5V and GND of the power supply, the AOUT pin is connected to the

analog input pin of ESP32 which is ADC1_0 whereas the DOUT pin is

not connected.

The HC-SR04 sensor also has four pins; VCC, GND, TRIG

(trigger pin), and ECHO (echo pin). The VCC and GND are connected to

the 5V and GND of the power supply, and TRIG and ECHO pins are

connected to the GPIO pins of ESP32 which are D12 and D13,

respectively.

The YF-S201 sensor typically has three pins; VCC, GND, and

Signal pin (data output pin). The VCC and GND are given 5V and the

GND of the power supply, where the signal pin is connected to the GPIO

pin of ESP32 is D33.

The single-channel relay module consists of three pins; VCC,

GND, and IN (signal input pin). Where the VCC and GND pins are

provided 3.3V and GND of the ESP32 and the IN pin is connected to the

GPIO pin of ESP32 which is D19.

The electric pump contains two wires that can be considered

positive and negative with respect to a fixed clockwise direction. The

pump and relay are interconnected. The positive end of the pump is

connected to the (-) negative end of the 12V battery, the (+) positive end

of the 12V battery is connected to the common (COM) terminal of the

relay and the remaining negative end of the pump is connected to the

normally open (NO) terminal of the relay.

There are two pins given in the circuit for the purpose to tell

whether the litter-raking should be initiated or not. These pins are the

output signal pin and GND pin that are connected to GPIO pin D26 of

ESP32 and GND pin respectively.

Lastly, the NX4832T035 LCD contains four pins; VCC, GND,

TX (transmitter pin), and RX (receiver pin). The VCC and GND pin are

provided 5V and GND from the power supply. On the other hand, the

remaining pins are connected to the ESP32 microcontroller through a

UART (serial) communication interface namely TX2 and RX2 pins.

### 3.1.1.2. Working of Processing Unit

The DHT22 operates on capacitive humidity sensing and uses a

thermistor for temperature measurement. Inside the sensor, a humidity-

sensitive capacitor's dielectric properties change with varying humidity

levels, leading to a variation in capacitance. The sensor also includes a

temperature-sensitive resistor (thermistor) to measure the surrounding

temperature. When exposed to the air, moisture is absorbed by the

sensor's humidity-sensitive material, affecting the capacitance, while the

thermistor's resistance changes with temperature. The sensor's internal

microcontroller processes these analog signals, converting them into

digital data representing humidity and temperature, which is then

transmitted to ESP32.

The MQ135 sensor works on the principle of a chemiresistor,

where its internal sensing material's electrical resistance changes when it

comes into contact with the target gas. The presence of the gas leads to a

variation in the resistance, and by measuring this change, the sensor can

infer the concentration of the gas. The analog output of the sensor is

directly proportional to the concentration of the detected gas, and

calibration is essential to ensure accurate readings. This output is then

sent to ESP32.

In the HC-SR04 sensor, the TRIG pin is an output from the ESP32

that sends a short pulse to trigger the sensor, and the ECHO pin is an

input to the ESP32 that receives the echo signal back from the sensor. To

measure the distance, the ESP32 sends a short pulse to the TRIG pin,

which triggers the HC-SR04 to emit an ultrasonic sound wave. The sound

wave travels through the air, hits the liquid present in the bottle, and

bounces back. The ECHO pin then receives the reflected sound wave, and

the ESP32 measures the time it took for the sound wave to travel back.

Using the speed of sound and the time of flight, the ESP32 can calculate

the distance to the object.

The YF-S201 flow sensor operates based on the Hall effect. Inside

the sensor, there is a magnetic rotor that spins as water or fluid flows

through the sensor. The rotor contains magnets, and as it spins, it

generates pulses. The sensor has a Hall effect sensor to detect these

pulses. The more pulses per unit of time, the higher the flow rate. By

measuring the time between pulses, the flow rate of the liquid passing

through the sensor can be calculated.

An HW-307B single-channel relay module is working as an

electrically controlled switch that can be used to turn ON or OFF the

electric pump using a low-power control signal. The relay consists of a

coil and a switch. When a control signal from the ESP32 energizes the

relay's coil, it creates a magnetic field, causing the switch to change

position, and closing the circuit on its output terminals.

When the relay is activated (energized) through a control signal

from a microcontroller or switch, it completes the circuit, allowing the pump to receive power and operate. A 12V DC electric pump is working

by converting electrical energy from the 12V DC power supply into

mechanical energy to pump fluids. The pump contains an impeller or

diaphragm that creates a pressure difference, causing the fluid to be

drawn into the pump and then expelled through the pump's outlet. The

pump's operation is driven by an electric motor, which rotates the

impeller or moves the diaphragm, depending on the pump's design.

The fluid is then transferred to both nozzles allowing them to

spray the fluid in the form of mist or fog.

When the ammonia level reaches 25 ppm, the pin for litter-raking

gets high indicating litter-raking should be enabled. The pin only gives

two values that are high and low dependent on the ammonia level.

The ESP32 communicates with the Nextion display using serial

communication, exchanging data and commands to control the display,

update its content, and receive touch input. The ESP32 sends appropriate

commands to the display to show text, images, buttons, and other

graphical elements. When the user interacts with the touchscreen, the

display sends touch data back to the ESP32, allowing the microcontroller

to respond accordingly.

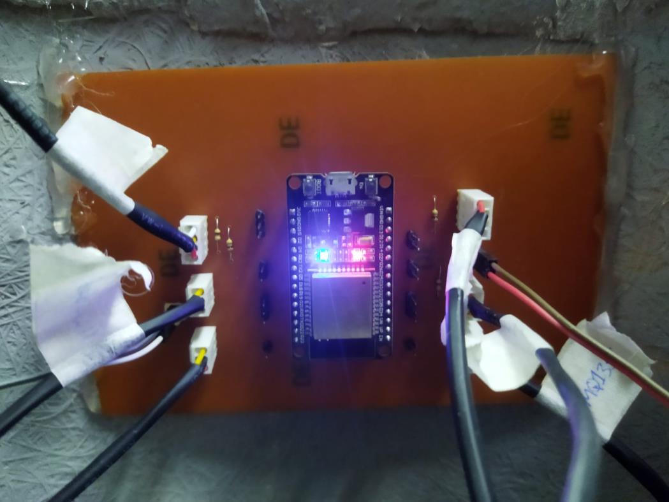
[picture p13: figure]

Figure 3.2 Complete Circuit of Processing Unit Integrated on the Fabricated PCB is Enabled

### 3.1.2. Power Supply Unit

The components used in the power supply unit are Li-Ion 3S4P Battery

Pack, HX-3S-FL25A-A Protection Board, XL-4016 DC-DC Step-Down

Converter, and 3S Battery Level Indicator.

### 3.1.2.1. Connections in Power Supply Unit

Li-ion 3S4P battery pack is created using 12 individual Murata

VTC6A 21700 lithium-ion cells with matching capacities and voltage

ratings. Three cells are connected in series to create 3S and for 4P, four

groups of 3S are connected in parallel. All the cells are connected with

nickel strips that are electrically welded on the terminals of cells. The

entire battery pack is then balanced using a balanced charger that

balanced each cell.

The HX-3S-FL25A-A protection board is connected to each cell

in the battery pack to provide safety features and monitoring capabilities.

It has six terminals; B-, B1, B2, B+, P+ and P-. The B- and B+ are battery

negative and positive terminals that are connected to the 0V and 12V of

the battery pack, respectively, where the B1 and B2 are the connection for

each cell for 3S. The B1 is considered as 4V which is connected to the

positive end of the cell whose negative end is connected to B- on the

other hand, B2 is considered as 8V which is connected to the positive end

of the cell whose negative end is connected to B1 making the B+ to be

considered as 12V for the series connection of 3S battery pack. Only left

with P+ and P- are power output connections as positive and negative

terminals, respectively.

The XL4016, a high-performance step-down buck converter

integrated circuit (IC), is connected to a Li-ion 3S4P battery pack by

wiring the battery's positive terminal to the XL4016's input voltage pin

and connecting the battery's negative terminal to the IC's ground pin. The

buck converter's voltage is then stepped down to 5V using its

potentiometer.

Lastly, the 3S battery level indicator is connected to a Li-ion 3S4P

battery pack by tapping into the positive and negative terminals of the

pack. Since it can connect batteries ranging from 1S to 8S therefore, the

required 3S is enabled by shorting it with its own circuitry as provided.

### 3.1.2.2. Working of Power Supply Unit

The resulting battery pack delivers increased overall capacity and

remains at a 12V output. When in use, the cells discharge in unison, and the parallel arrangement enhances the discharge current capability. In this

configuration, the parallel connection increases the capacity, while the

series connection boosts the voltage.

The protection board continuously monitors the voltage and

current of each cell, cutting off the current flow in case of dangerous

conditions, such as overcharging or discharging beyond safe limits, to

prevent damage or thermal runaway. It ensures the safe and balanced

operation of the Li-ion battery pack, enhancing its overall performance

and lifespan.

The XL4016 regulates the input voltage (12V-5V) from the 3S Li-

ion battery pack efficiently and delivers a continuous output current

suitable for the connected load. By utilizing pulse width modulation

(PWM) technology, the XL4016 achieves high conversion efficiency,

minimizing power losses. The regulated voltage is then supplied to all the

other components having 5V as the operating voltage.

The battery level indicator is designed to monitor the voltage of

the entire 3S battery pack, as it is connected in parallel to the series-

connected sets. By measuring the overall voltage, the indicator determines

the charge level of the entire battery pack. It provides visual feedback,

typically through LEDs, indicating the remaining charge and enabling

users to assess the battery's status.

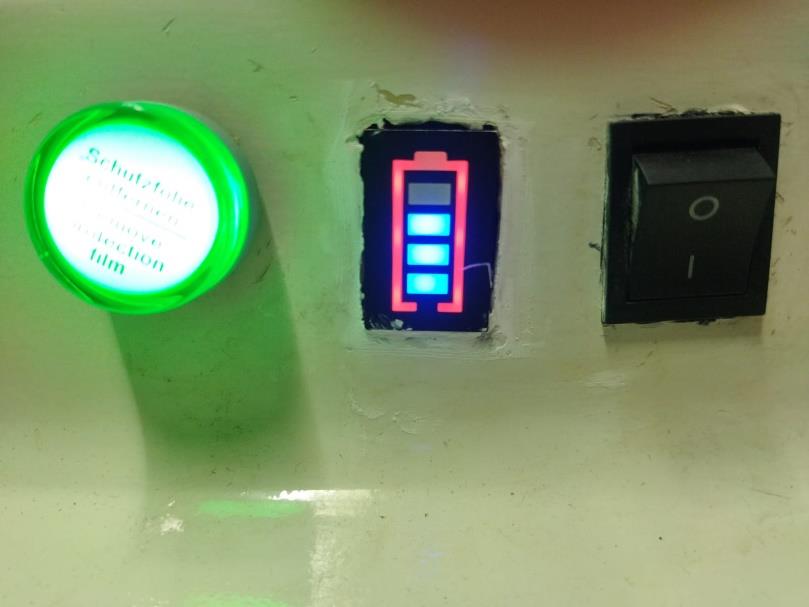
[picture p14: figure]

Figure 3.3 Indication of Power Supply Unit Controlled through Switch along with Battery Level Indicator Indicating 75% Charging Remaining

### 3.1.3. Live-Streaming Unit

The component used in the live-streaming unit is ESP32-CAM.

### 3.1.3.1. Connections in Live-Streaming Unit

The operating voltage of ESP32-CAM is 5V which is provided by the

power supply.

### 3.1.3.2. Working in Live-Streaming Unit

The camera captures video frames and stores them in its memory. The

ESP32 module, equipped with Wi-Fi capabilities, establishes a

connection to a network, allowing users to access the camera remotely.

The captured media is streamed to a web server or directly to a

smartphone application, offering real-time surveillance or remote

monitoring capabilities.

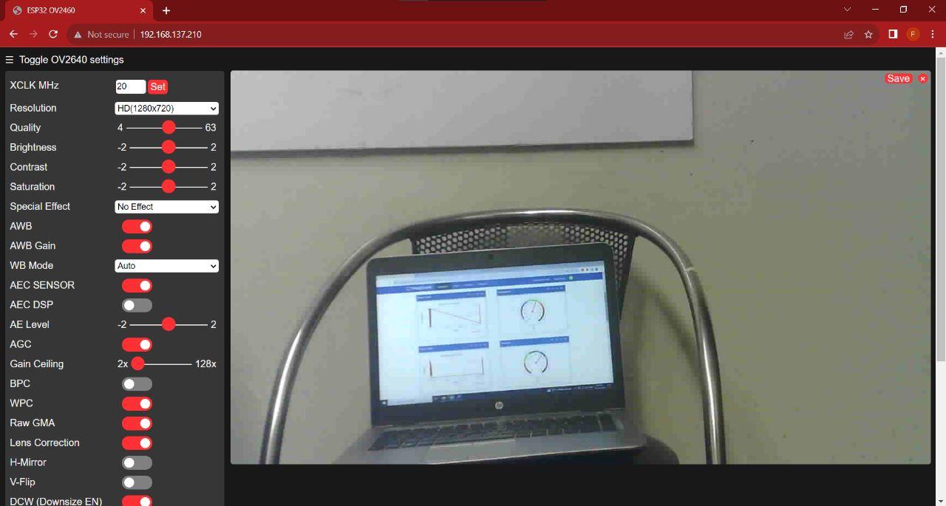
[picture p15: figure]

Figure 1 Live-Streaming Seen on the Local IP Address by ESP32-CAM

### 3.2. Details of Software Implementation

The software implementation details are as follows:

### 3.2.1. Arduino Software

Arduino IDE is used to upload respective codes in ESP32 to test all

the components. In the respective library according to the sensor included, the

pin(s) are defined, and code is created as per use. The code is then uploaded

by selecting the ESP32 board, the baud rate and the port interconnected with

the device and ESP32. The components tested are temperature and humidity

sensor, air quality sensor, ultrasonic distance sensor, liquid flow rate sensor,

nextion HMI LCD, single-channel relay module, and the camera module.

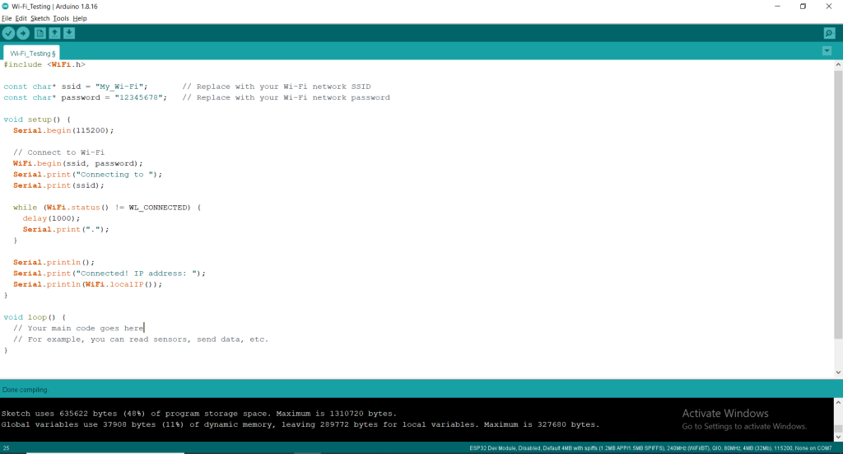
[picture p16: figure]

Figure 3.2 Wi-Fi Testing on Arduino IDE

### 3.2.2. ThingSpeak

A channel is created on ThingSpeak (IoT Cloud Platform) where a

graphical user interface has been designed according to the parameters and

available gadgets that helps in readibilty. The data of all four sensors that are

DHT22 (Temperature and Humidity Sensor), MQ135 (Air Quality Sensor),

HC-SR04 (Ultrasonic Distance Sensor), and YF-S201 (Liquid Flow Rate

Sensor) are displayed on ThingSpeak (IoT Platform) with the help of read

API provided by ThingSpeak. The values of all the parameters; temperature,

humidity, ammonia level, liquid storage capacity, and liquid flow rate is

updated according to the change.

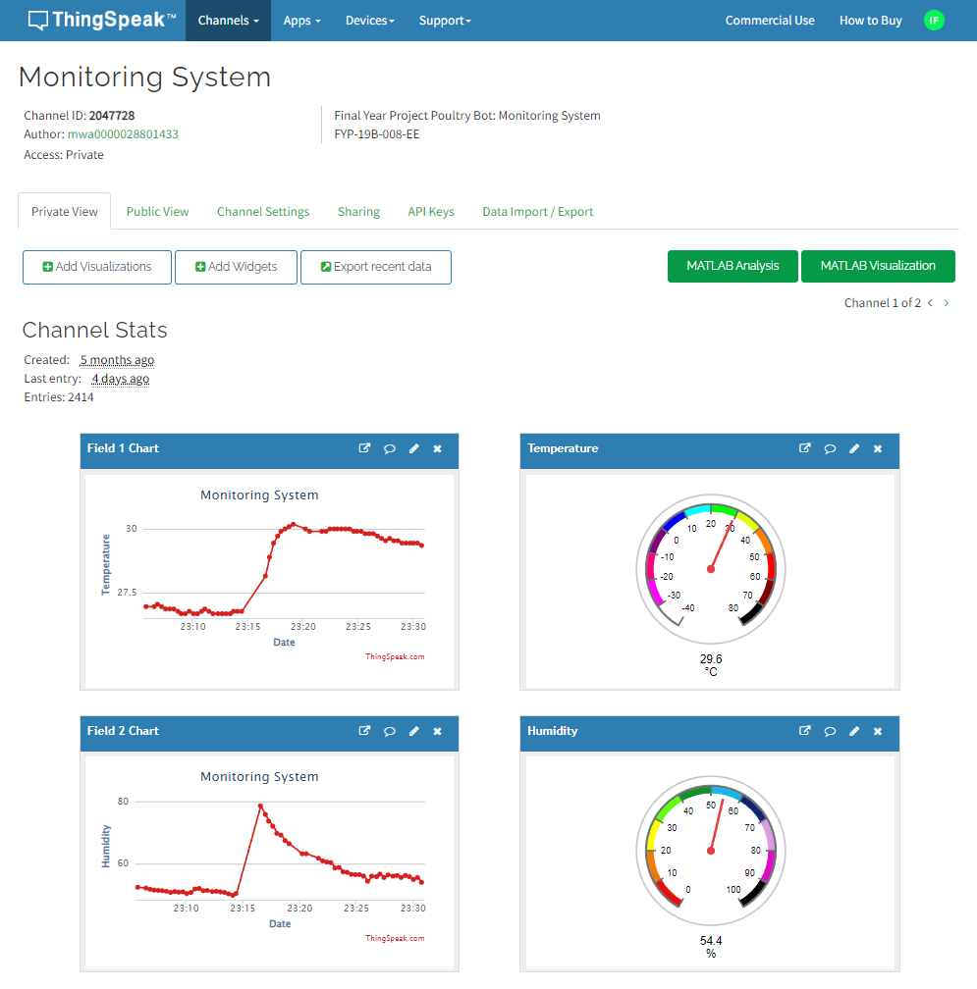
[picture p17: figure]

Figure 3.3 Temperature and Humidity Monitoring in ThingSpeak

### 3.2.3. Nextion Editor

A file Nextion Editor is created consisting of a number of pages along

with a home page. Each page contains a visual representation of data sent by

ESP32 taken from sensors. The graphics include background images, text,

buttons, gauges, a progress bar, sliders, scrolling text, and variables. A few

lines of code were written to switch pages and to update the values and

graphics of the parameters. Once the GUI is designed, the Nextion Editor

compiles the project into a binary file (".tft"), ready to be uploaded to the

Nextion display via microSD card or serial communication. This file is then transferred to the LCD with the help of an SD card through an SD card port

of the LCD, powered on so that the GUI can be transferred easily. Once the

file is saved in the LCD the SD card was removed providing the GUI where

the data can be received and the touch data can be transmitted via serial

communication.

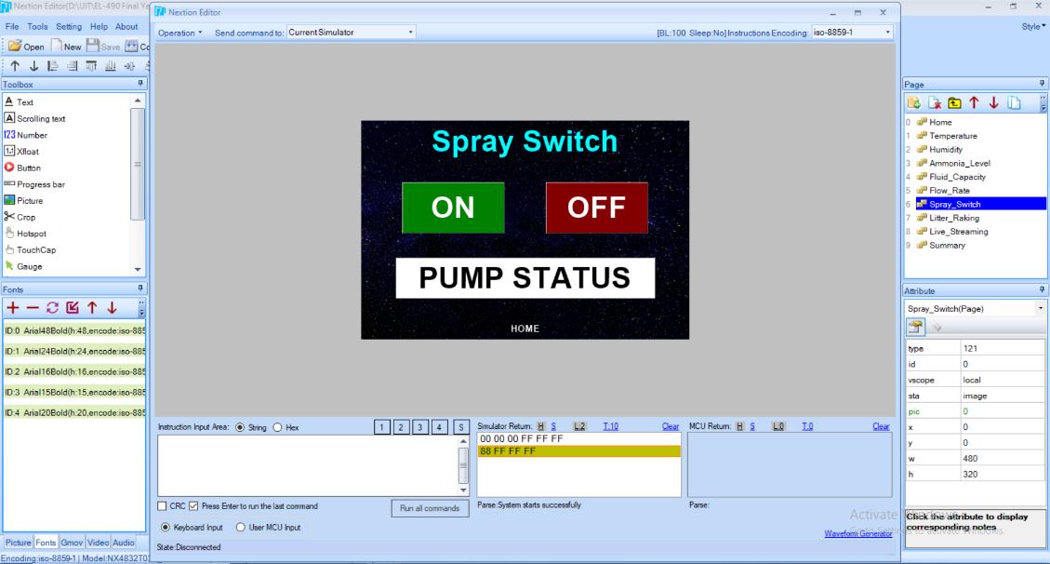
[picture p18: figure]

Figure 3.4 On Off Buttons Debugging in Nextion Editor

### 3.2.4. Visual Studio Code

The main code has been written on VS Code for ESP32 and IoT. It

contains all the included libraries, the definition of all the pins, separate

functions as per the required operations of each component, and some special

functions such as time delays. A special extension “programio” has been

included that helps the VS Code getting the arduino boards. For the IoT

purpose, it also contains the user id and password of Wi-Fi to send data to

ThingSpeak through the provided API. Furthermore, the code is also able to

respond to the touch of the LCD where the pump is controlled from the LCD.

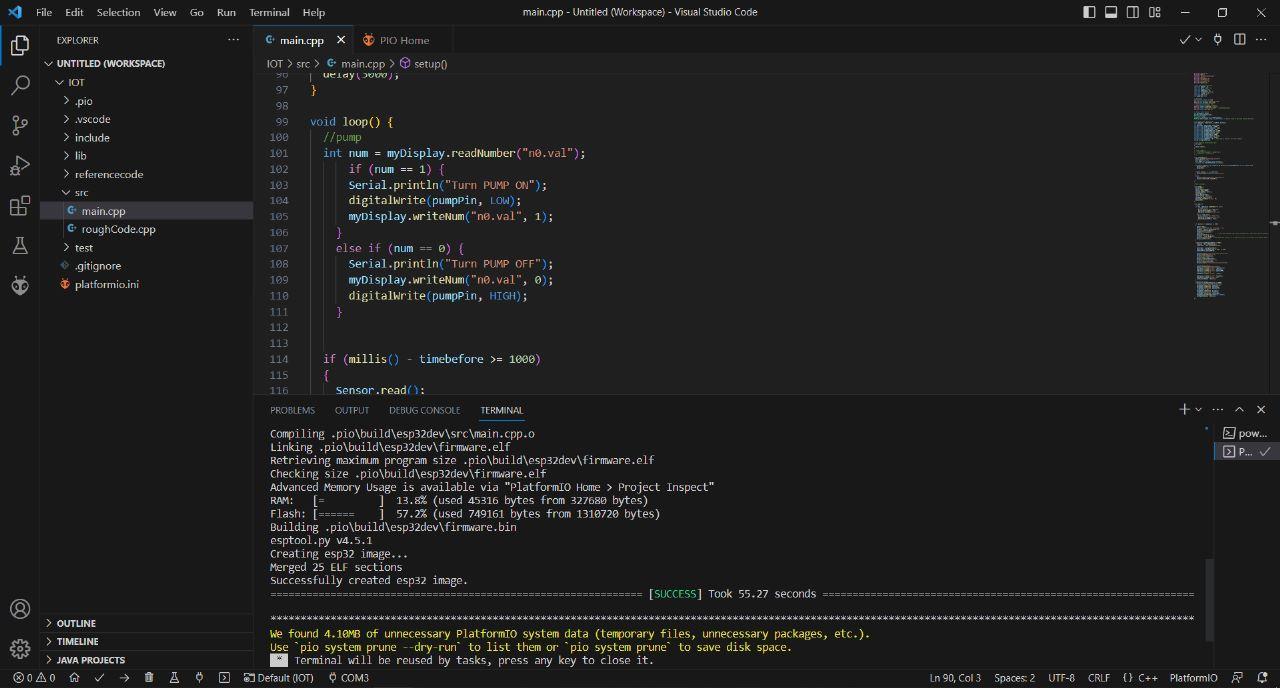
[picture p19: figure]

Figure 3.5 Code Compiling in VS Code

### 3.2.5. Ki-Cad

Ki-CAD software is used to design PCB layouts for the circuitry. First

of all, a new Ki-CAD file is created that contains a schematic layout and PCB

layout. Considering the schematic layout, a schematic diagram has been

constructed by placing components from the library and connecting them

with the help of wires. To convert the schematic to PCB layout, after the

establishment of connection, the components are annotated for their identity

and then the footprints of the components are assigned from the footprints

library. Then a netlist file has been generated completing the task on

schematic layout. Coming towards the PCB layout, the generated netlist file

has now been imported that contains footprints of all the components and

their connections. The components are then arranged according to the desired

output, the traces have been created between the components on the copper

layer, and finally, some text has been written on the silkscreen layer to make

the PCB layout look good and unique. After the completion of the PCB layout, the Gerber files and drill files have been generated and imported so

that the PCB of the circuit can be made physically.

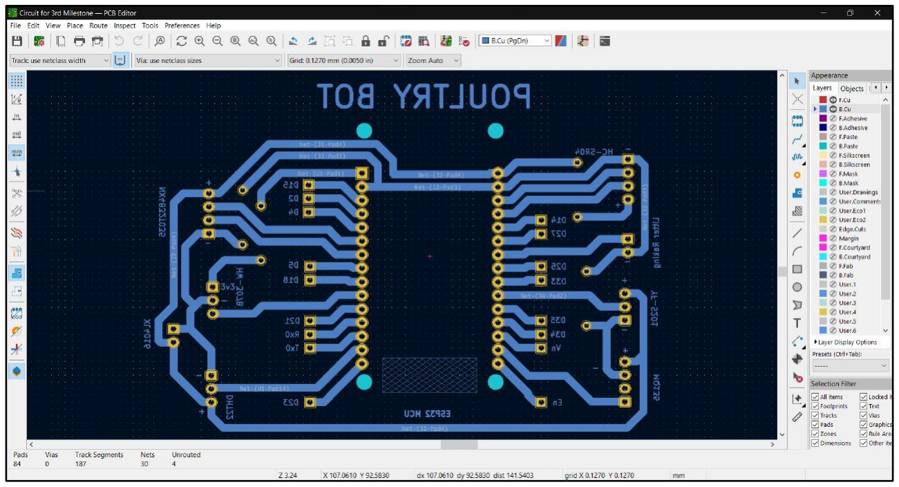
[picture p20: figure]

Figure 3.6 PCB Layout Designing in Ki-CAD

### 3.2.6. MIT App Inventor

MIT App Inventor is a specialized software from which a remote

control app has been created. This app contains a GUI where controls of a

remote and a small window for live streaming of ESP32-CAM can be seen

taken from the numerous provided features of the app. The window is

enabled by providing it the IP address of the local server generated by the

ESP32-CAM. On the other hand, the controls that are forward, backward,

left, and right are used to control the motion of the robot manually along with

upward, downward and enabling switch for litter-raking. The app also

provides simple drag-and-drop coding from which the buttons have been

coded according to their operation. Since the remote control is connected

with Bluetooth so, several lines of code are also written comprised of

Bluetooth connection establishment along with Wi-Fi interfacing. After the

GUI and code have been completed, the app has been downloaded easily in the (".apk") extension provided by the app which is compatible with Android.

This file is then installed in the Android mobile for manual controlling of the

robot through remote control.

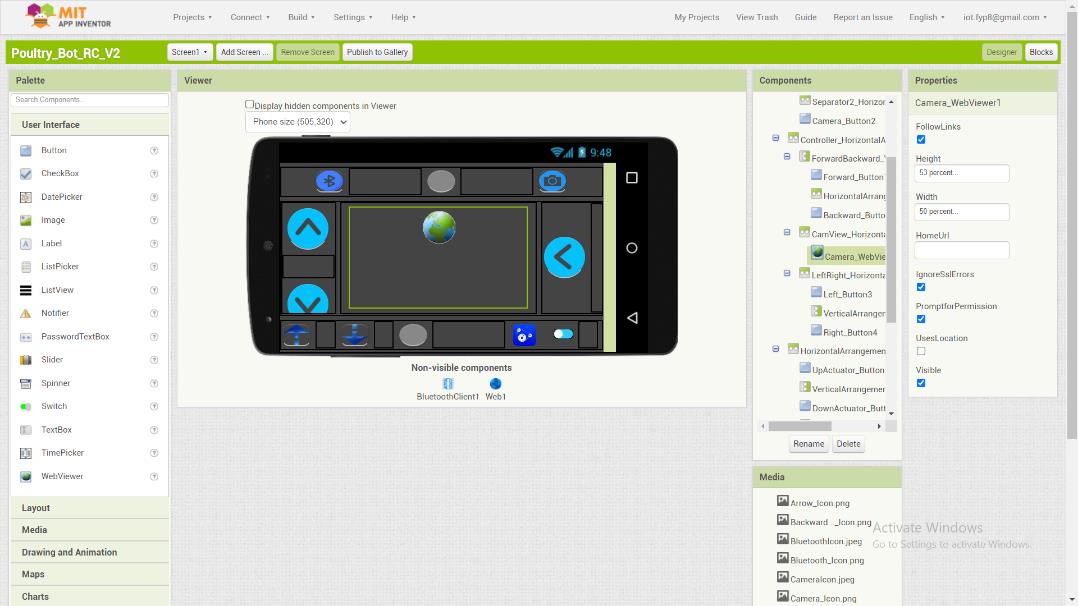
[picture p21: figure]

Figure 3.7 Remote Control Designing in MIT App Inventor

# CHAPTER # 04

## PROJECT CHARACTERIZATION

### 4.1. Results Obtained

The results obtained in the project are similar to what was expected. The

monitoring of all the parameters; temperature, humidity, ammonia level, liquid

storage capacity in the water bottle, and liquid flow rate through the electric pump

has been monitored successfully by finely sending the data to the IoT cloud platform

and HMI LCD simultaneously where the change in values can be observed.

Furthermore, the electric pump has been controlled from the manual switch

integrated into the HMI LCD. Last but not least, the live streaming has been seen

victoriously on the remote control app that controls the poultry bot when tends to be

controlled manually.

The images of the results obtained are following:

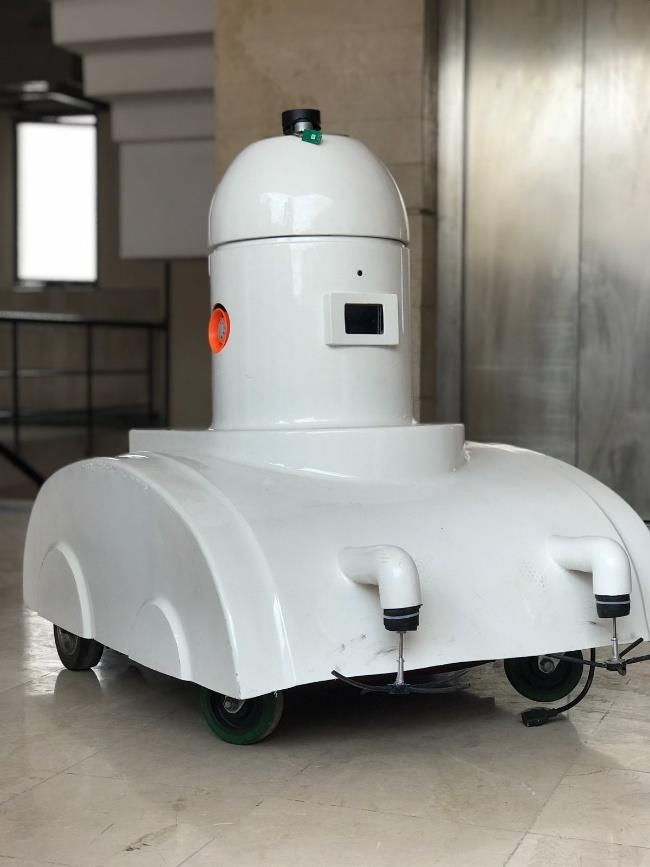
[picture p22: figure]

Figure 4.1 Image of Robot Structure Displaying Nextion HMI LCD, Camera Module, and Two Spray Nozzles (In Orange Color) on Left and Right

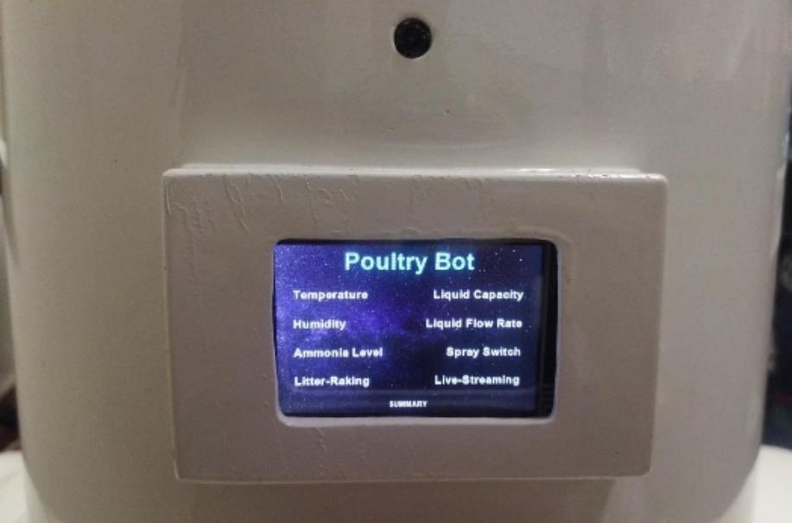
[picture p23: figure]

Figure 4.2 Image of Nextion HMI LCD (Bottom) and Camera Module (Top) Integrated in the Structure

### 4.2. Analysis

The monitoring parameters that are temperature, humidity, ammonia level,

liquid storage capacity in the water bottle, and liquid flow rate through an electric

pump were first to be displayed on Blynk IoT but due to difficulties in connection

with ESP32 the IoT Cloud Platform was changed to ThingSpeak. Furthermore, the

data readability on HMI LCD was not that easy including the integration of the

control button. Coming towards the app, it was not an easy nut to crack, the design of

GUI was not that drag and drop instead defining horizontal and vertical layout as per

the requirements. Lastly, a few problems occurred while working on the software as

these were new to us so learning and implementing was quite a great challenge.

### 4.3. Conclusion

In conclusion, the implementation of IoT monitoring is a very small example

of Industrial Revolution 4.0 to make the industry automated and to be controlled

remotely. The parameters which are monitored, include temperature, humidity,

ammonia level, liquid capacity of the storage tank, and liquid flow rate through the electric pump. The purpose of temperature is to cross-check whether the temperature

is maintained in the control shed or not on the other hand humidity helps to

determine whether the moisture absorbers should be placed or not. The ammonia

level is a very crucial parameter based on which litter-raking takes place as the

increase in ammonia level is harmful to the health of birds. The remaining two

parameters are situated in the spraying unit where the storage capacity defines the

quantity of liquid and the liquid flow rate determines the area covered by the spray.

Coming towards the live streaming feature, it can provide the user view of the entire

poultry farm without any human interaction. Last, but not least, the remote control

app is a wonderful feature that allows the user manually controlling of the robot

along with integrated options of litter-raking control and live-streaming view.

### 4.4. Future Recommendations

In the future, a database can be created to have a record of all the monitoring

parameters on an hourly, daily, weekly, or monthly basis. The electric pump which is

manually controlled can be automated using machine learning where the liquid can

be sprayed considering the daily routine that when the spraying is done. The Wi-Fi

connection can be made strong with the integration of the LoRa (Long Range)

module expanding the shed coverage. Lastly, for the camera module, AI (Artificial

Intelligence) can be implemented to detect dead birds along with increasing the video

quality by replacing it with a high quality camera. Furthermore, the multiple cameras

could be used to have a 360 view of the robot as well as of the shed.

REFERENCES

[1] “AN OVERVIEW OF PAKISTAN POULTRY INDUSTRY YEAR 2020-2021 – Pakistan Poultry Association.” https://pakistanpoultryassociation.com.pk/news/an-overview-of-pakistan-poultry-industry-year-2019-2020/ (accessed Jun. 20, 2022).
[2] “Autonomous robotics for the poultry shed | The Poultry Site.”
https://www.thepoultrysite.com/articles/autonomous-robotics-for-the-poultry-shed (accessed Jun. 20, 2022).
[3] “Robots: the new frontier in poultry production | The Poultry Site.”
https://www.thepoultrysite.com/articles/robots-the-new-frontier-in-poultry-production (accessed Jun. 20, 2022).
[4] “Best New Poultry Farm Equipment – 7 Robot & Automation Products.” https://agsolarsolutions.com/best-new-poultry-farm-equipment-2019/ (accessed Jun. 20, 2022).
[5] “Poultry Technology: Rise of the robots - Canadian Poultry MagazineCanadian Poultry Magazine.” https://www.canadianpoultrymag.com/rise-of-the-robots-30876/ (accessed Jun. 20, 2022).
[6] R. Prasad Ch, “Internet of Things Based Home Monitoring and Device Control Using Esp32 Smart System Design View project Patents View project,” Int. J. Recent Technol. Eng., no. 8, pp. 2277–3878, 2019, Accessed: Jul. 24, 2023. [Online]. Available: https://www.researchgate.net/publication/334226986
[7] P. P. Ray, “A survey of IoT cloud platforms,” 2017, doi: 10.1016/j.fcij.2017.02.001.
[8] T. Bräunl, Embedded Robotics From Mobile Robots to Autonomous Vehicles with Raspberry Pi and Arduino, 4th ed. Perth: Springer Nature Singapore Pte Ltd., 2022.
[9] V. S. N. Reddy, S. P. Kumar, B. Venkat, and J. S. Priyanka, “IoT based social distance checking robot using Esp32-Cam,” AIP Conf. Proc., vol. 2407, no. 1, Dec. 2021, doi: 10.1063/5.0074056/624247.
[10] “PCB Design for Real-World EMI Control - Bruce R. Archambeault, James Drewniak -Google Books.”
https://books.google.com.pk/books?id=eIbdBwAAQBAJ&printsec=frontcover&source=gbs_vpt_buy#v=onepage&q&f=false (accessed Jul. 24, 2023).

APPENDIX A: (Complex Engineering Problem)

Appendix A1: Range of Resources

Table A1.1 Table of Range of Resources

Human Resource

S.No. | Discipline | Resource | Description
1 | Mechanical | Welder | Helped in constructing the mechanical structure of the litter-raking.
2 | Mechanical | Lathe Operator | Helped in coupling of litter raking motor.

Material/Equipment

S.No. | Discipline | Resource | Description
1 | Engineering Hardware | ● E-Tech Saddar ● Sher Shah Market ● Step Electronics | To purchase the electrical components and litter raking structure.

Reference Literature

S.No. | Discipline | Resource | Description
1 | Engineering | Articles / Books / Research Papers | Literature that provides sufficient information necessary to understand the working of human brain and emerging signals[6]–[10] .

Appendix A2: Innovation

This project is an innovation as it provides IoT monitoring, automatic spray,

and litter raking systems that ensure biosecurity in the poultry farm. The poultry farm

industry now is based on year-old practices and due to this productivity and

biosecurity welfare are affected. To overcome this issue the poultry bot automates

the general process of poultry farming and reduces human interaction. The process is

automated by the autonomous patrolling of the robot which reduces human

interaction. Furthermore, it automates the poultry farm industry and revolutionizes

the way poultry farming is conducted.

Appendix A3: Level of Interaction

In this project, new challenges were faced that are using the software first time

without any expertise so solving the occuring problems was a great issue. This issue

was solved by taking help from search engines, open-source projects and community

forums.

Appendix A4: Consequences to Society and the Environment

This project is built as an environment-friendly project obeying the SDG

(Sustainable Development Goals) of the UN (8,9 and 12). The sole purpose of this

project is to improve the biosecurity and production of the poultry farm. Through this

project, human interaction and effort are reduced which is beneficial for the

environment.

Appendix A5: Familiarity

The courses that we studied helped us significantly throughout the entire

project. The study of microprocessor-based systems helped us to initiate our project

toward the ESP32 microcontroller. For the programming, the C++ language learned

from the course programming fundamentals and its further implementation in the

course data structure and algorithms helped in writing fantastic code. Theories

learned from the course electrical machines helped in selecting motors and

successfully performing their operations. The understanding of power electronics

helped us in the manipulation of the DC voltage. Courses like linear circuit analysis,

digital logic design, electronic circuit design, and integrated electronics play great

role in circuit designing. The concepts of embedded systems assist us in IoT, which

heavily relies on it to function effectively. Finally, the skills learned from workshop

practice helped us in proper wiring, soldering, and mainly fabricating PCB.

APPENDIX B: PLAGIARISM REPORT

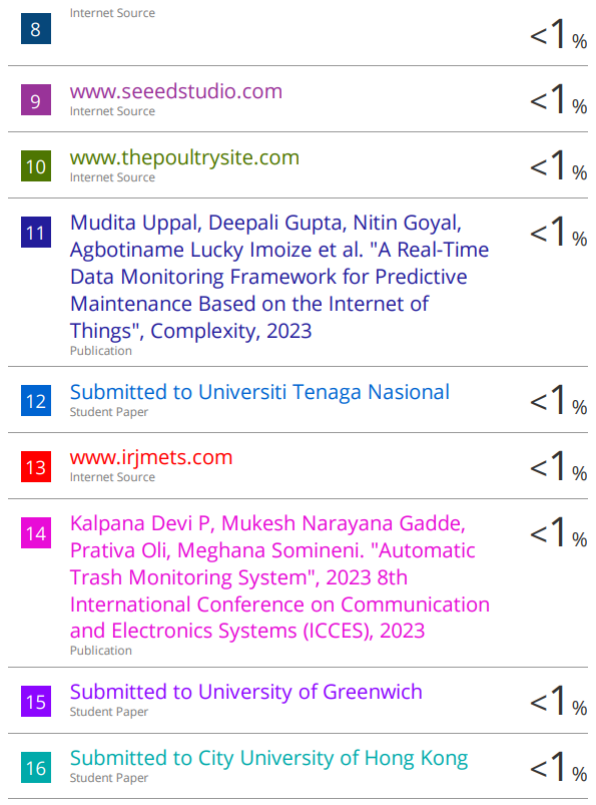
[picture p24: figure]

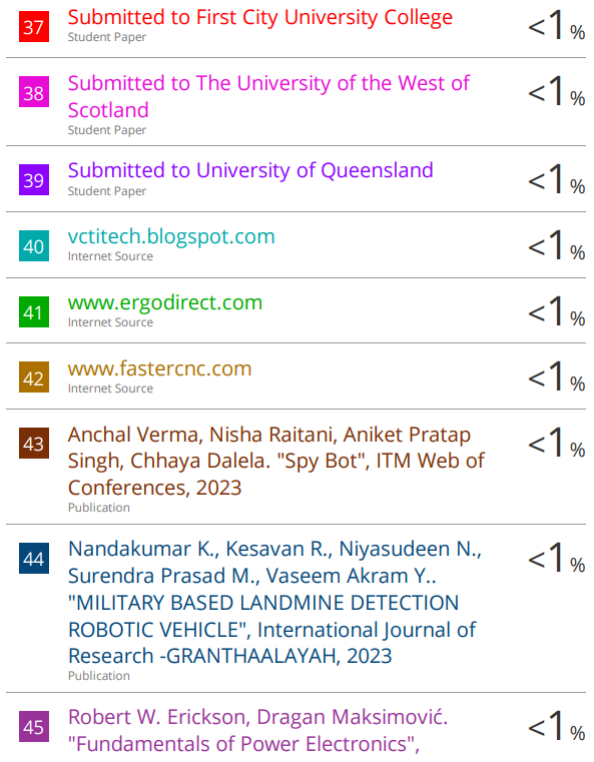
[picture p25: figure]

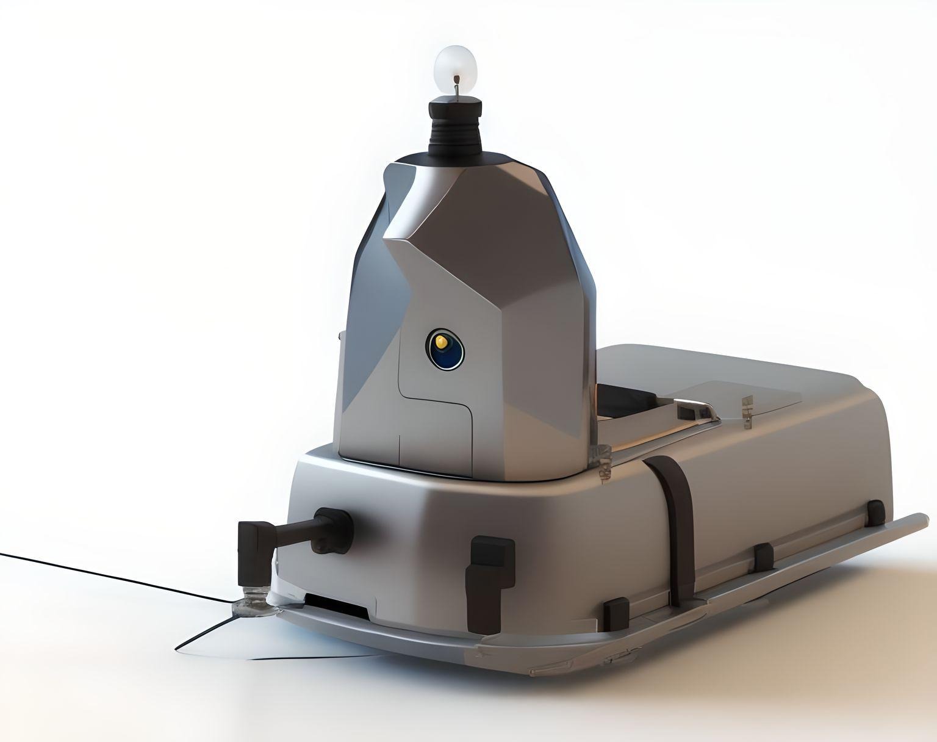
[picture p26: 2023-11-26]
ROS_based_Autonomous_System/Robot_Structure/Body/Design_2.jpeg

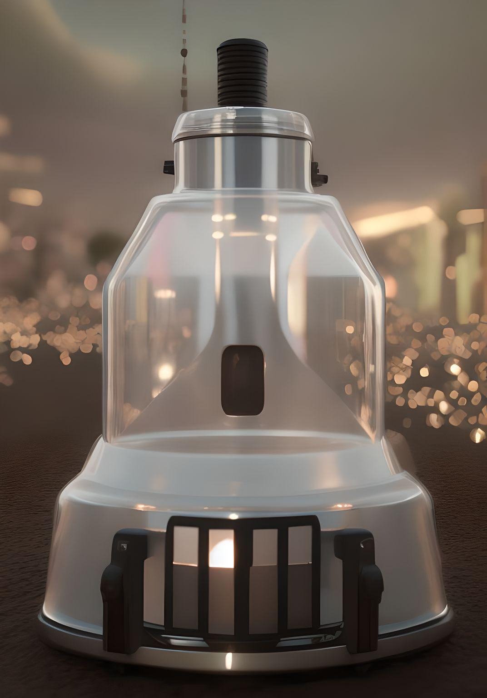
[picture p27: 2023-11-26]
ROS_based_Autonomous_System/Robot_Structure/Body/Design_1.jpeg

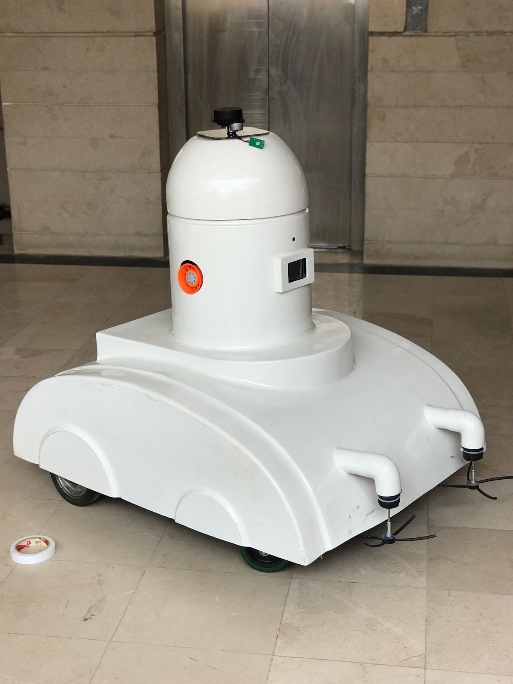
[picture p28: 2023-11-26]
Pics/Poultry_Bot_Pic_1.jpeg

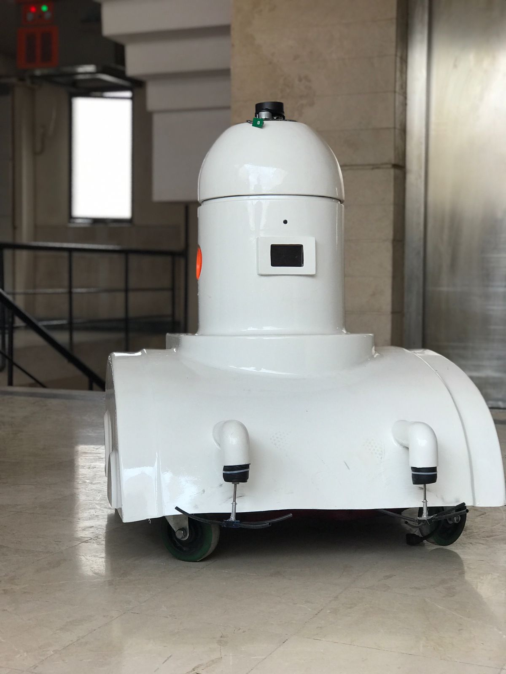
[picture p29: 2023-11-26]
Pics/Poultry_Bot_Pic_2.jpeg

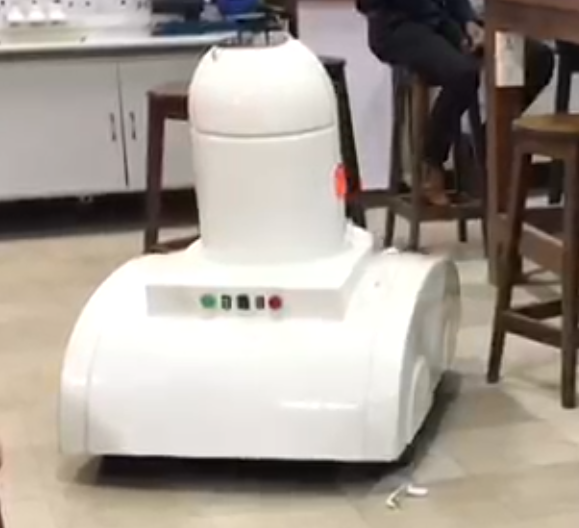
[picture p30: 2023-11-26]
Pics/Poultry_Bot_Pic_4.PNG

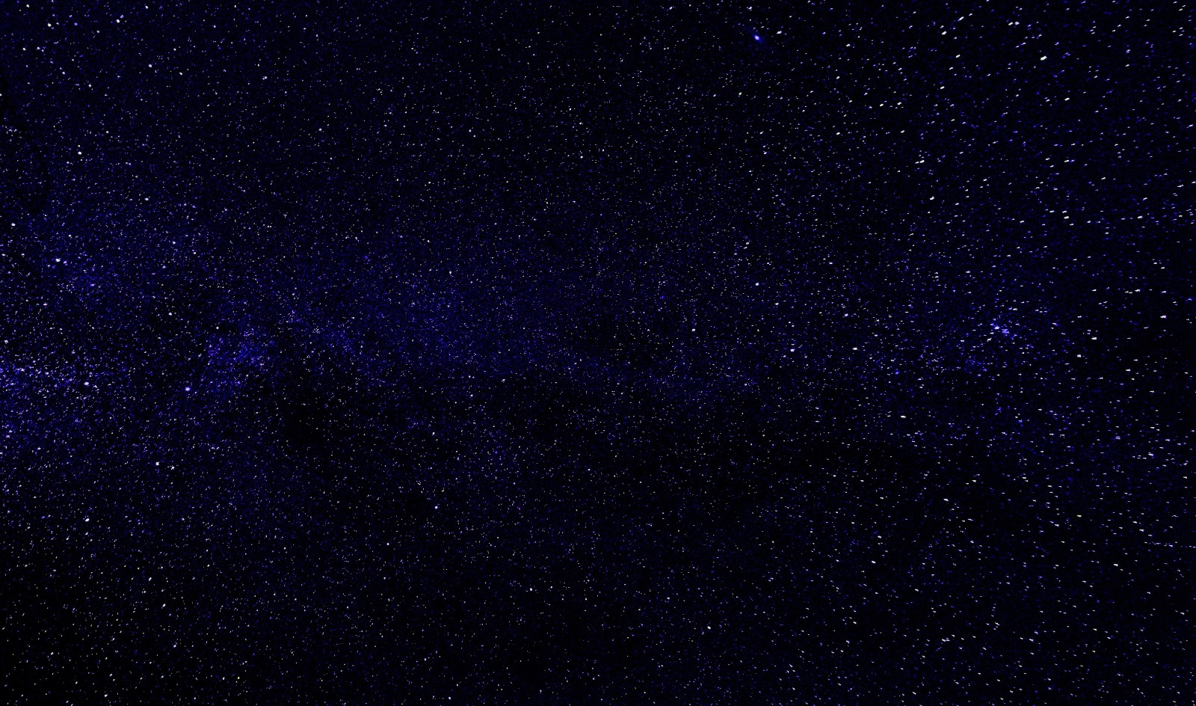
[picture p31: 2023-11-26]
IoT_Monitoring_System/Remote_Control_App/Poultry_Bot_Remote_Control_App/Background.jpeg

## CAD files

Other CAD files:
ROS_based_Autonomous_System/Robot_Structure/Complete.dwg
ROS_based_Autonomous_System/Robot_Structure/Base/Base_Modified.dwg
ROS_based_Autonomous_System/Robot_Structure/Body/Level_2.dwg
ROS_based_Autonomous_System/Robot_Structure/New_Design/Poultry_Bot_V2.dwg
ROS_based_Autonomous_System/Robot_Structure/Base/Wheel.dwg
ROS_based_Autonomous_System/Robot_Structure/Body/Level_1.dwg
ROS_based_Autonomous_System/Robot_Structure/Base/Base.dwg

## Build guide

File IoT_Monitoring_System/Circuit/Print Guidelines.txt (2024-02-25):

LAYERS
******

Normal
======
Back Copper

Mirrored
========
Front Copper
Front Silkscreen

DRILLS
******

From Top (Normal)
=================
Non-Plated Through Hole
Plated Through Hole

From Bottom (Mirrored)
======================
Non-Plated Through Hole
Plated Through Hole

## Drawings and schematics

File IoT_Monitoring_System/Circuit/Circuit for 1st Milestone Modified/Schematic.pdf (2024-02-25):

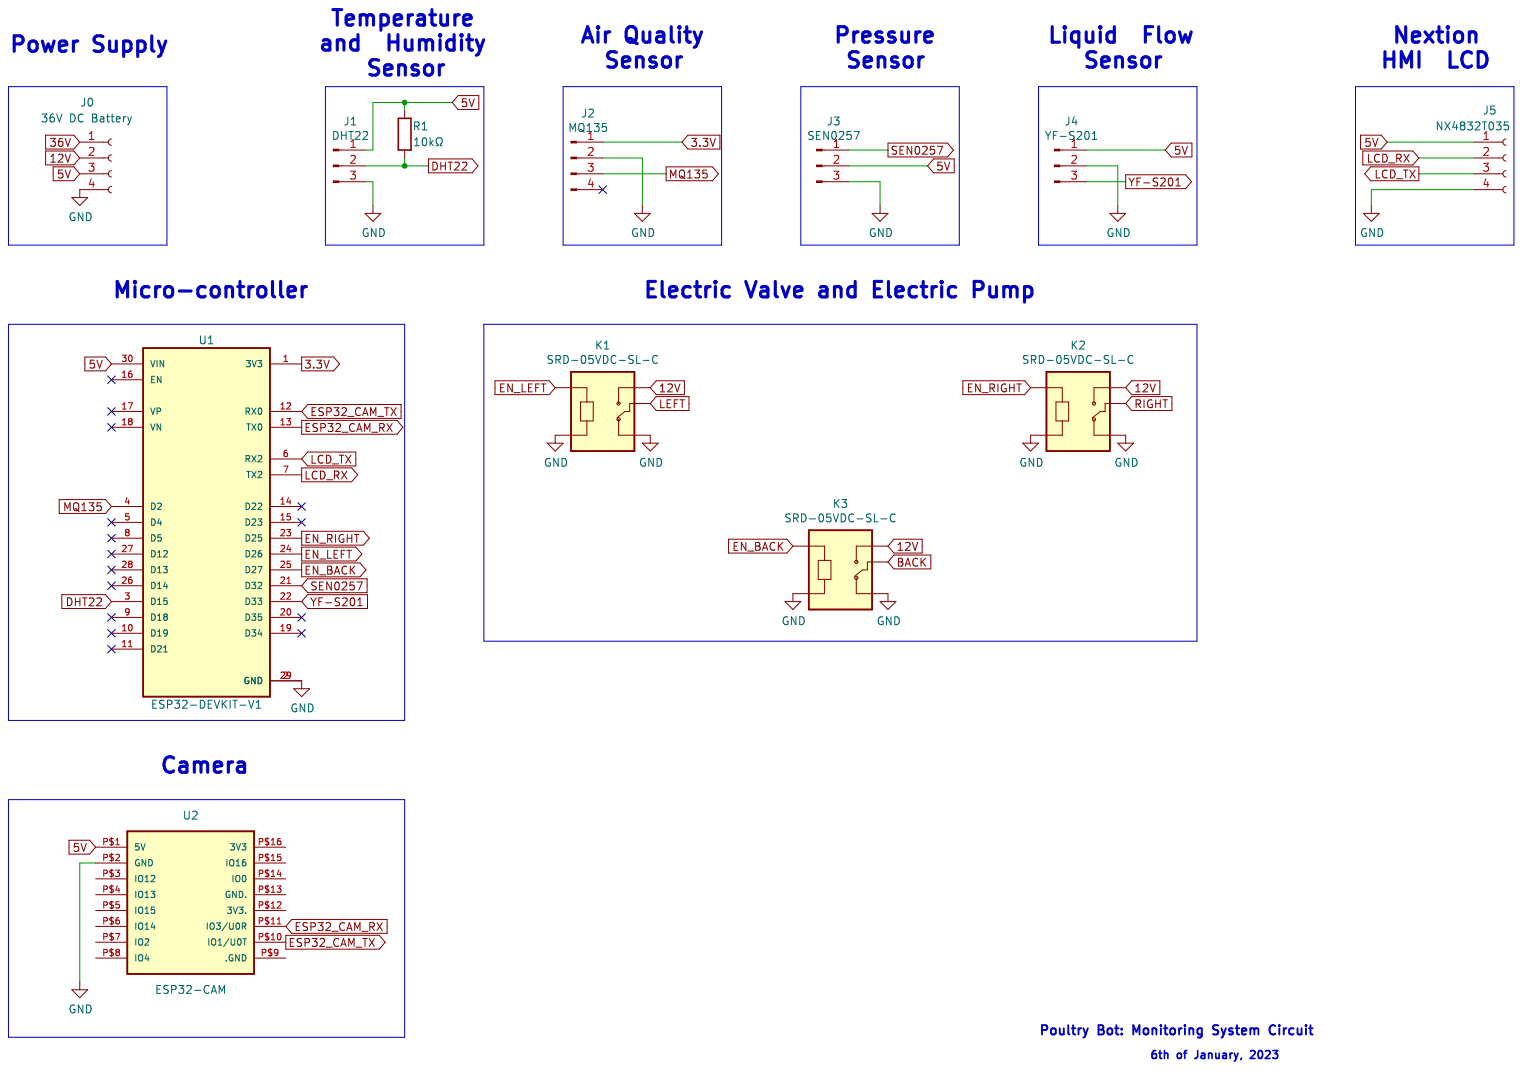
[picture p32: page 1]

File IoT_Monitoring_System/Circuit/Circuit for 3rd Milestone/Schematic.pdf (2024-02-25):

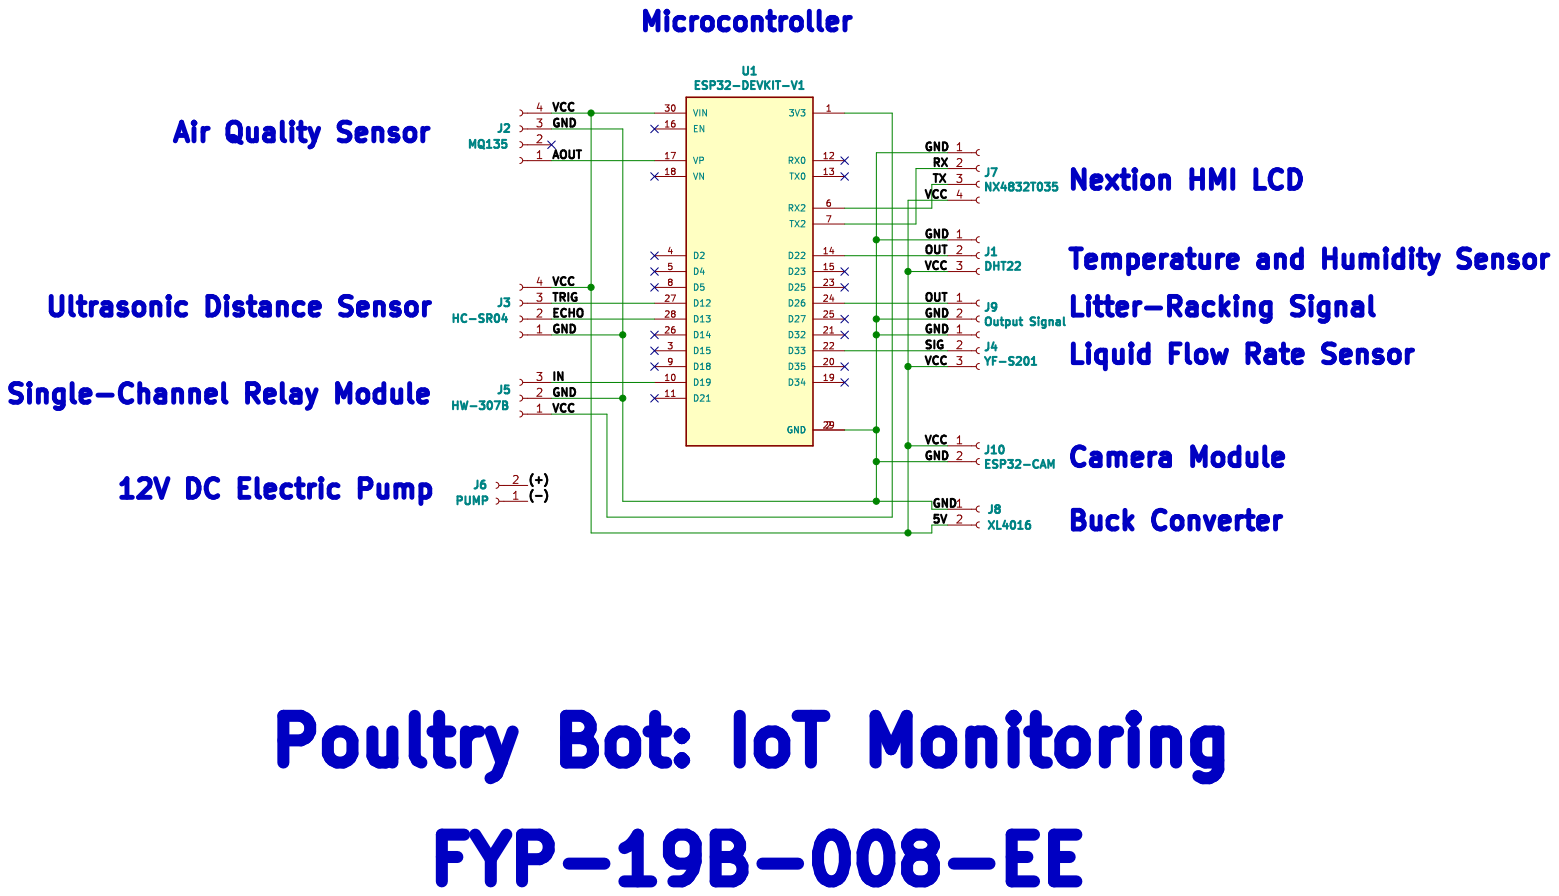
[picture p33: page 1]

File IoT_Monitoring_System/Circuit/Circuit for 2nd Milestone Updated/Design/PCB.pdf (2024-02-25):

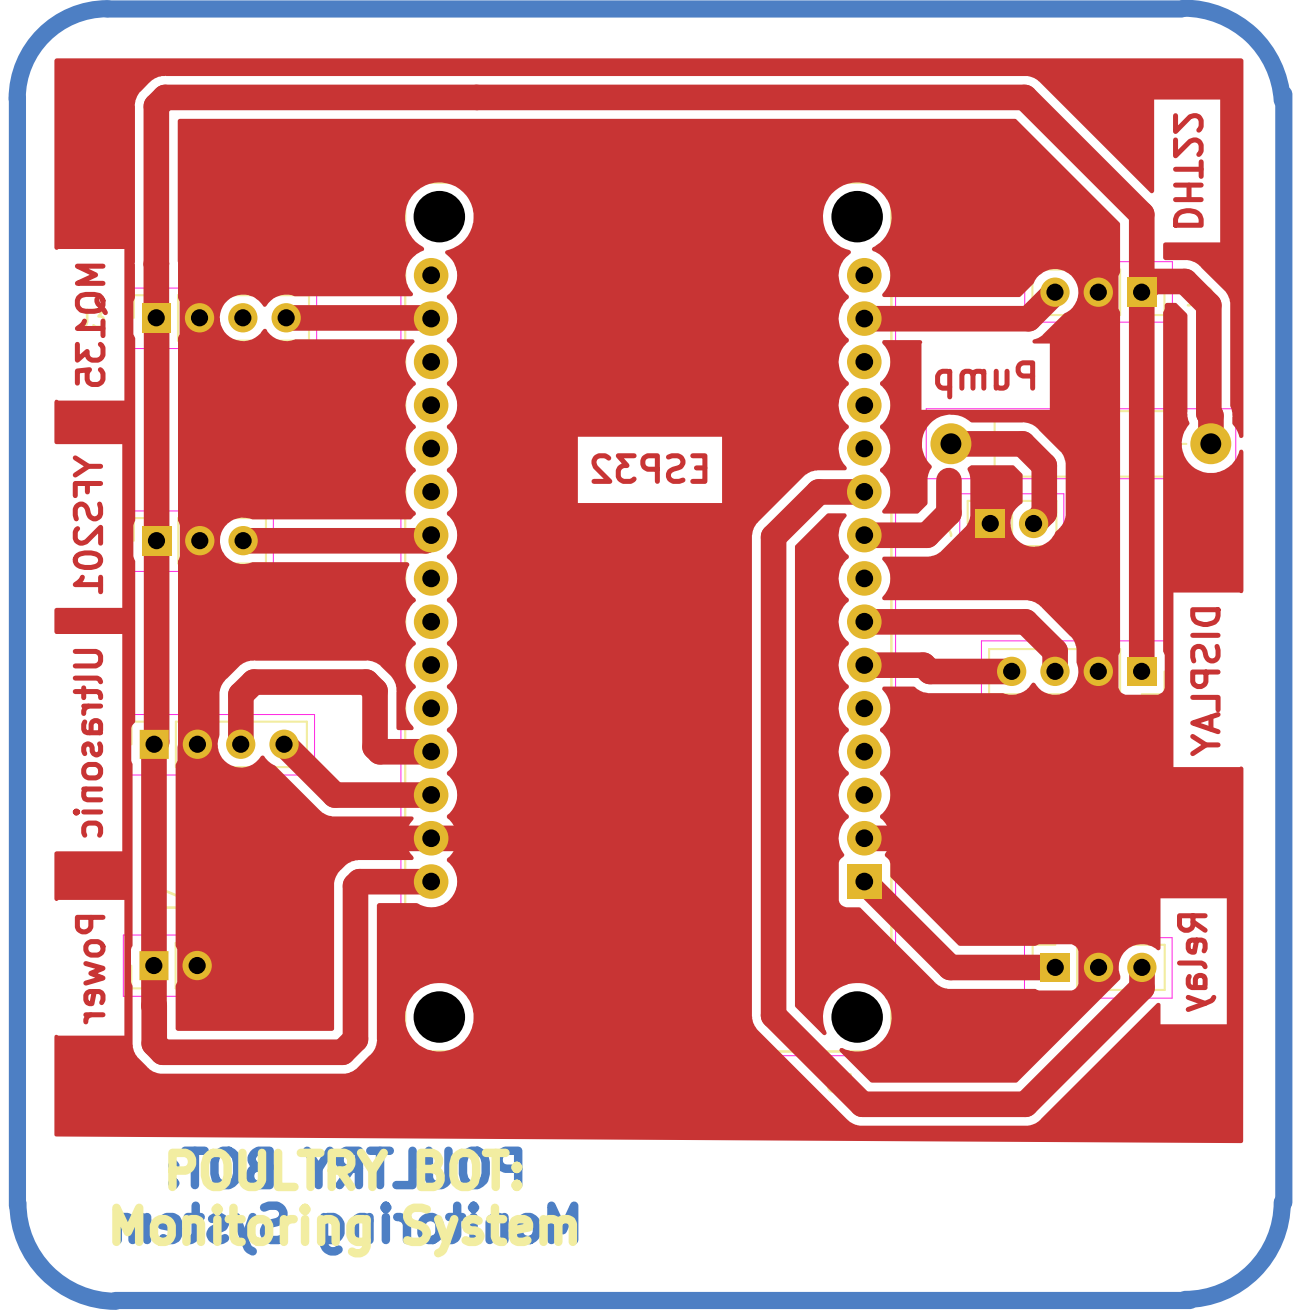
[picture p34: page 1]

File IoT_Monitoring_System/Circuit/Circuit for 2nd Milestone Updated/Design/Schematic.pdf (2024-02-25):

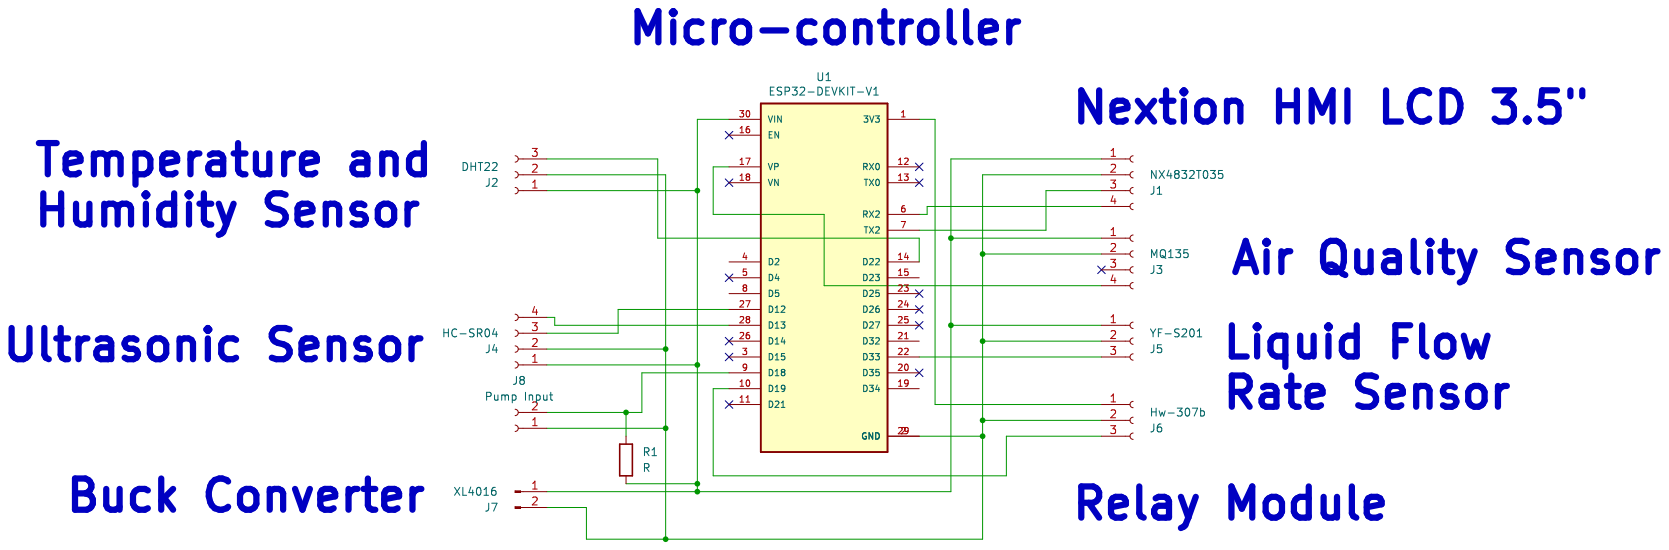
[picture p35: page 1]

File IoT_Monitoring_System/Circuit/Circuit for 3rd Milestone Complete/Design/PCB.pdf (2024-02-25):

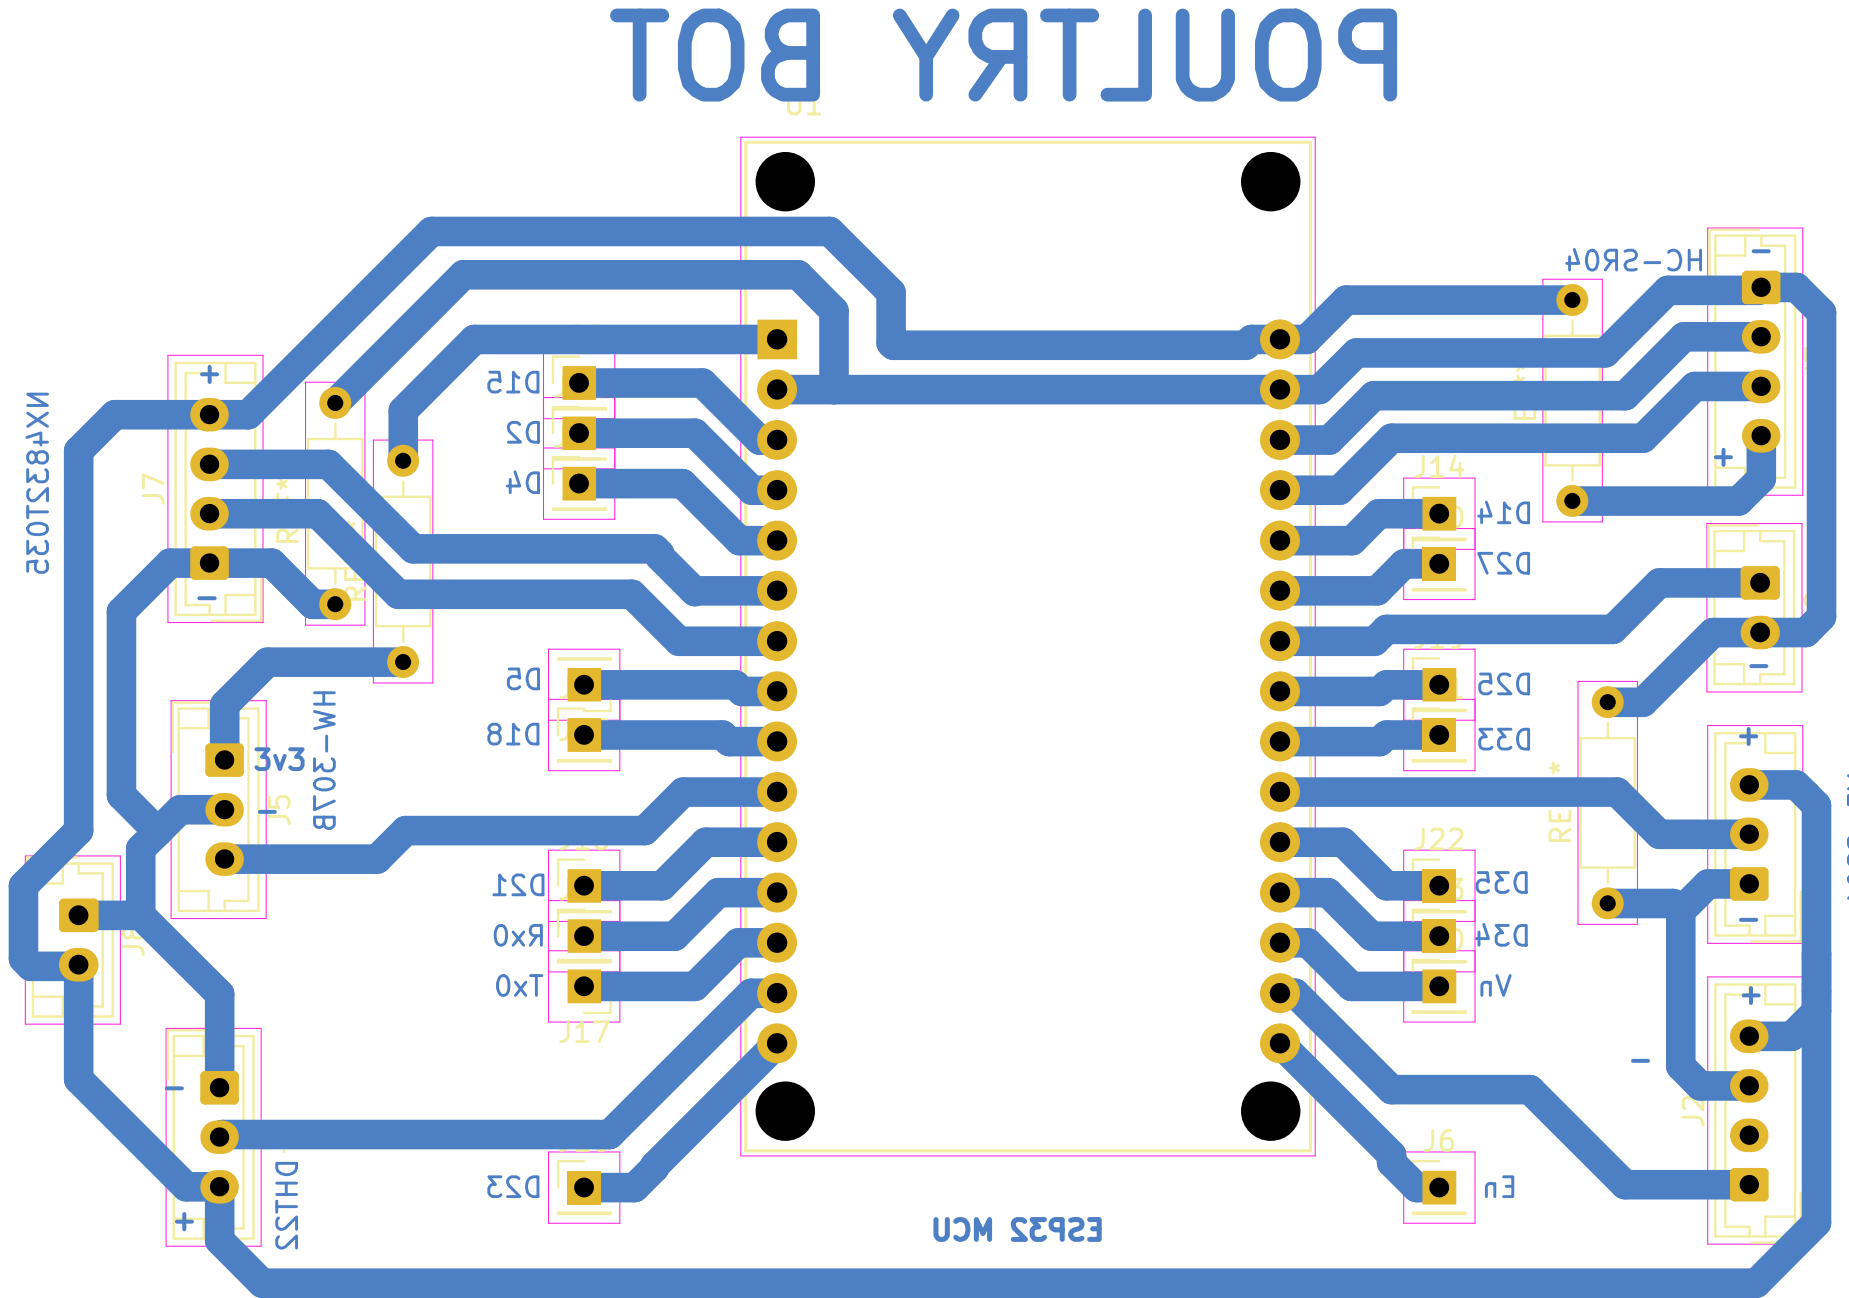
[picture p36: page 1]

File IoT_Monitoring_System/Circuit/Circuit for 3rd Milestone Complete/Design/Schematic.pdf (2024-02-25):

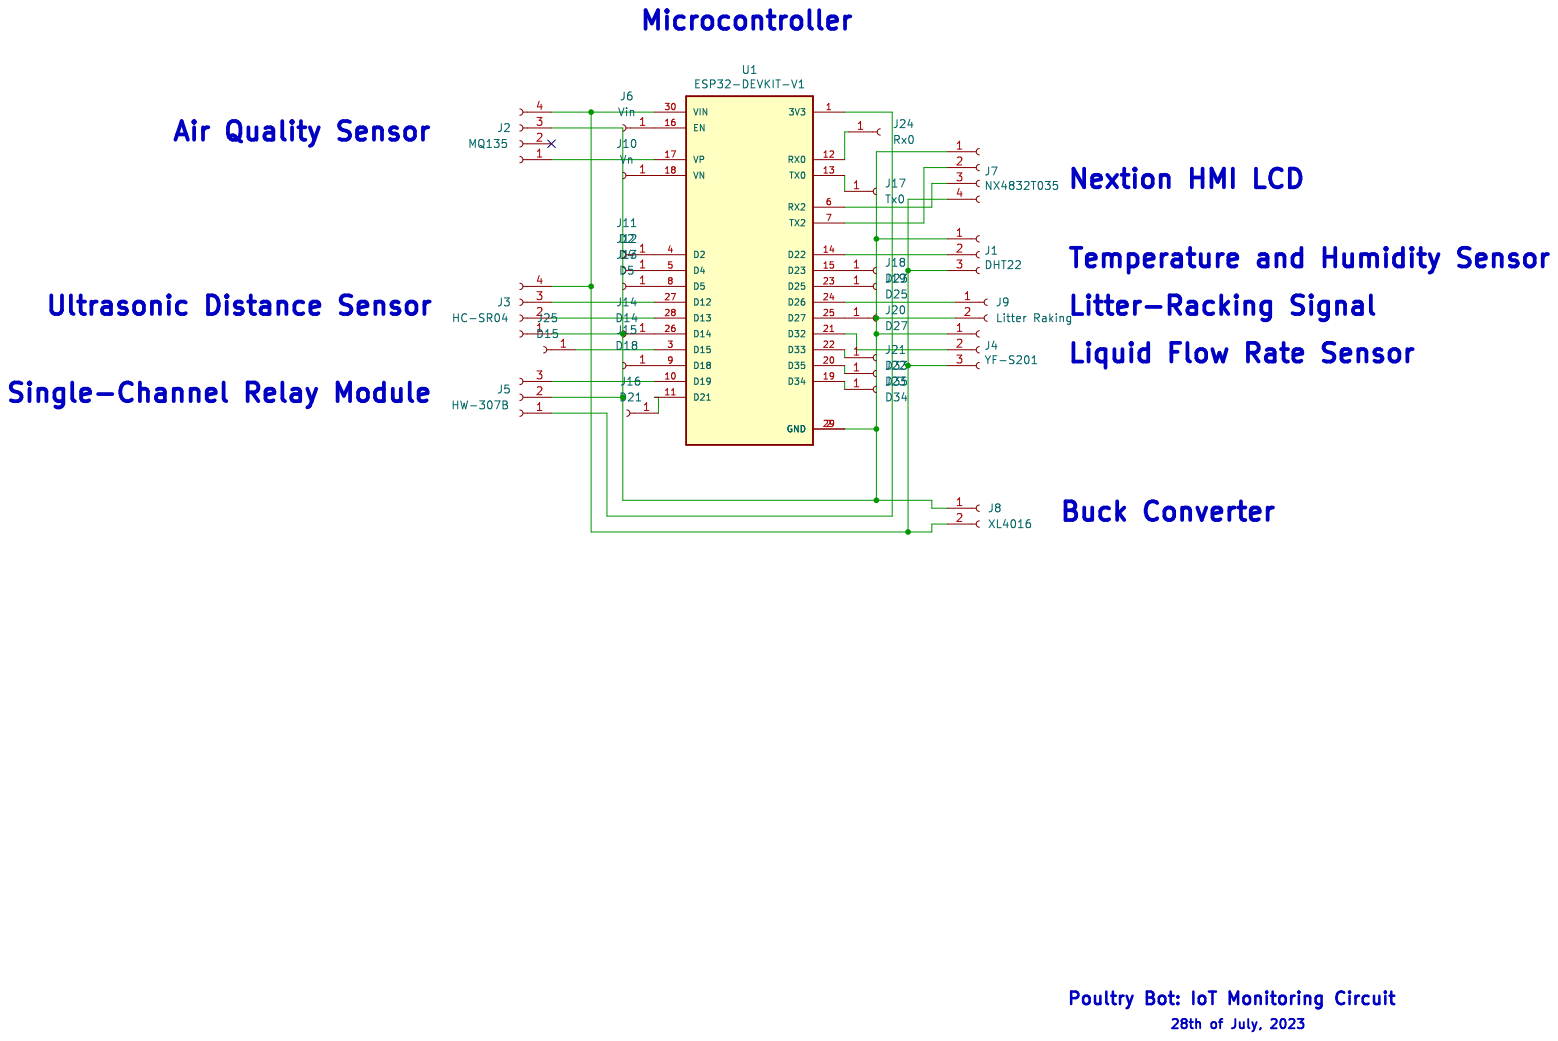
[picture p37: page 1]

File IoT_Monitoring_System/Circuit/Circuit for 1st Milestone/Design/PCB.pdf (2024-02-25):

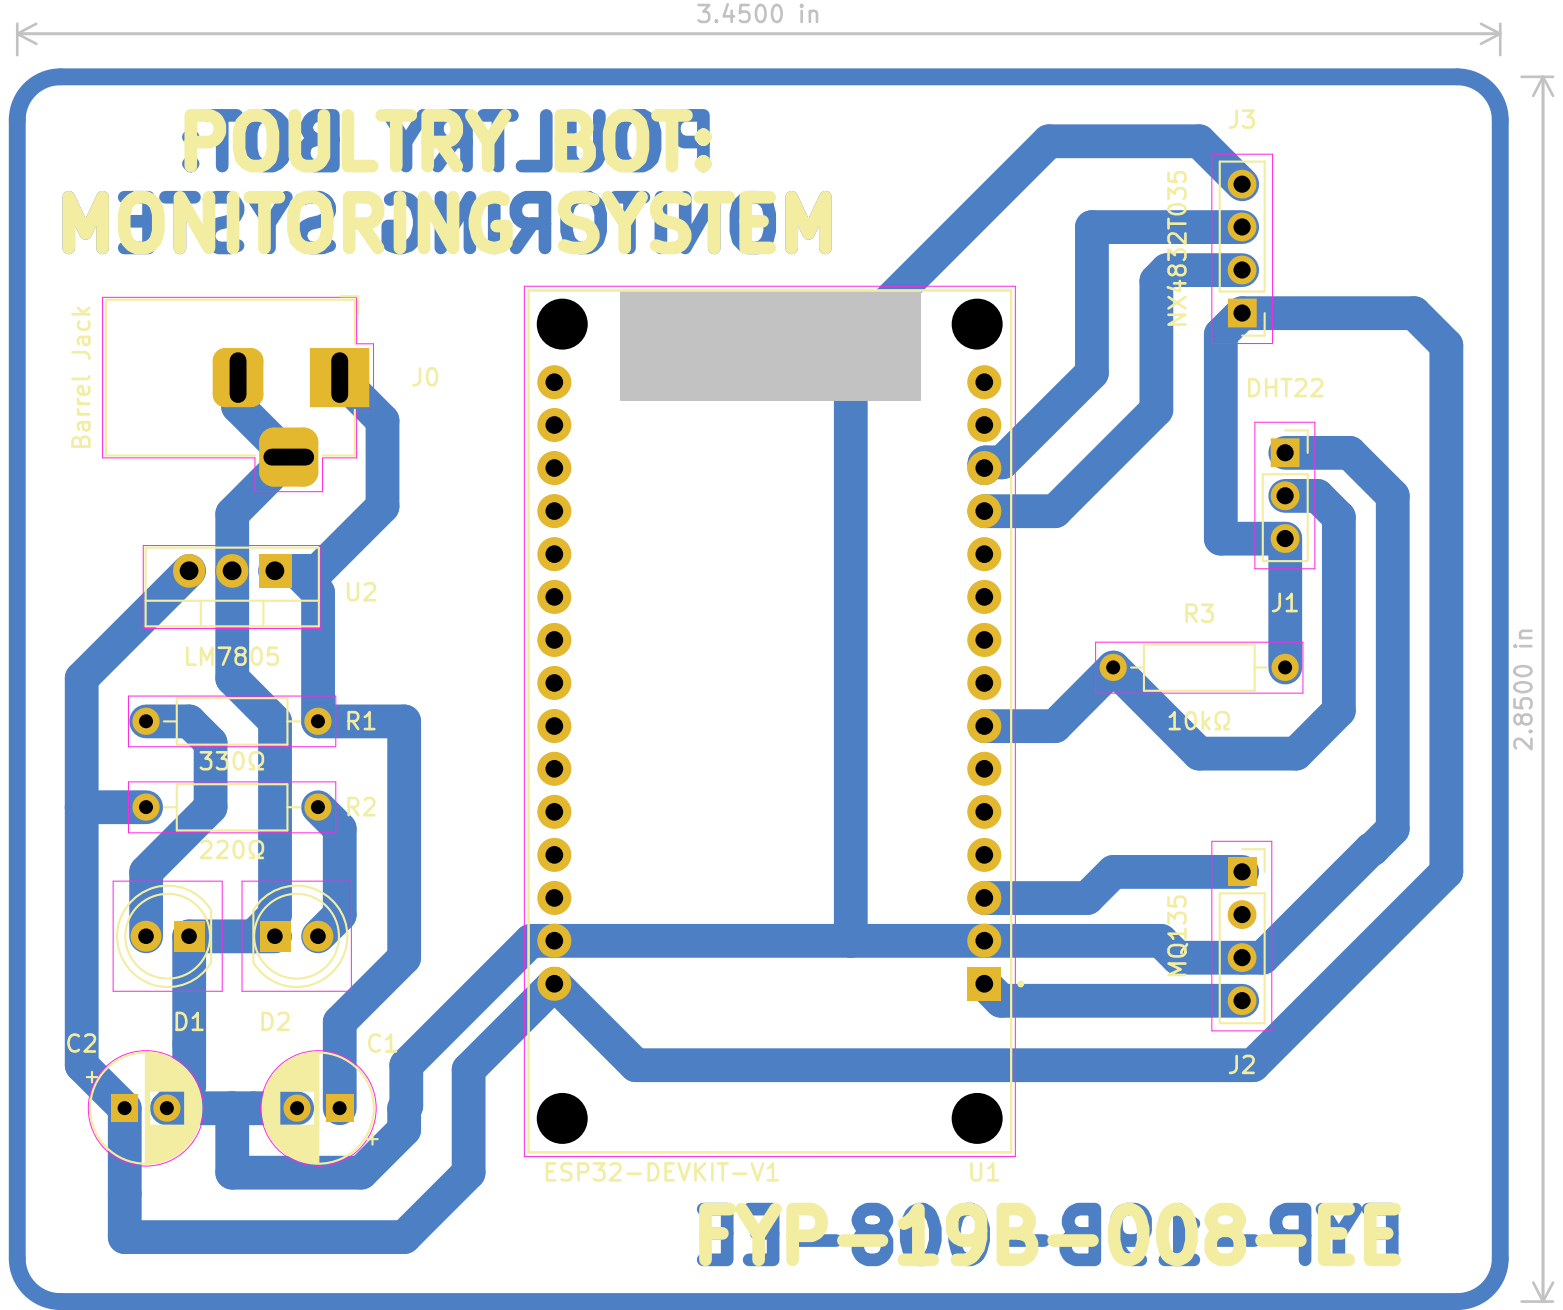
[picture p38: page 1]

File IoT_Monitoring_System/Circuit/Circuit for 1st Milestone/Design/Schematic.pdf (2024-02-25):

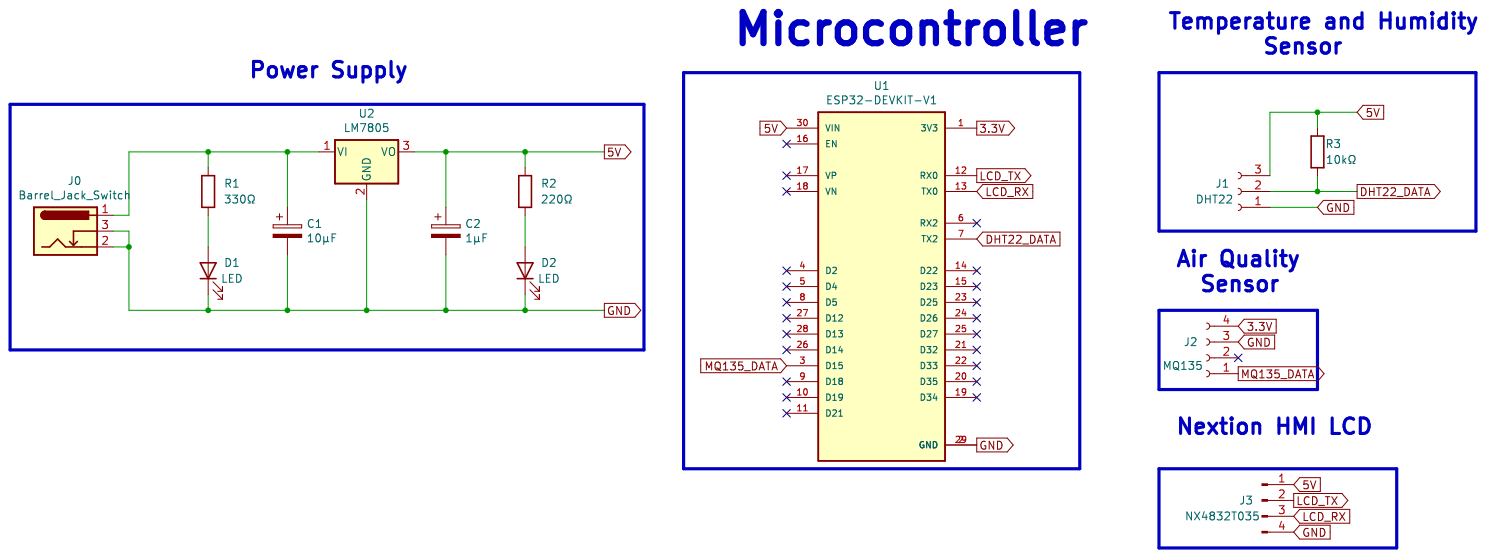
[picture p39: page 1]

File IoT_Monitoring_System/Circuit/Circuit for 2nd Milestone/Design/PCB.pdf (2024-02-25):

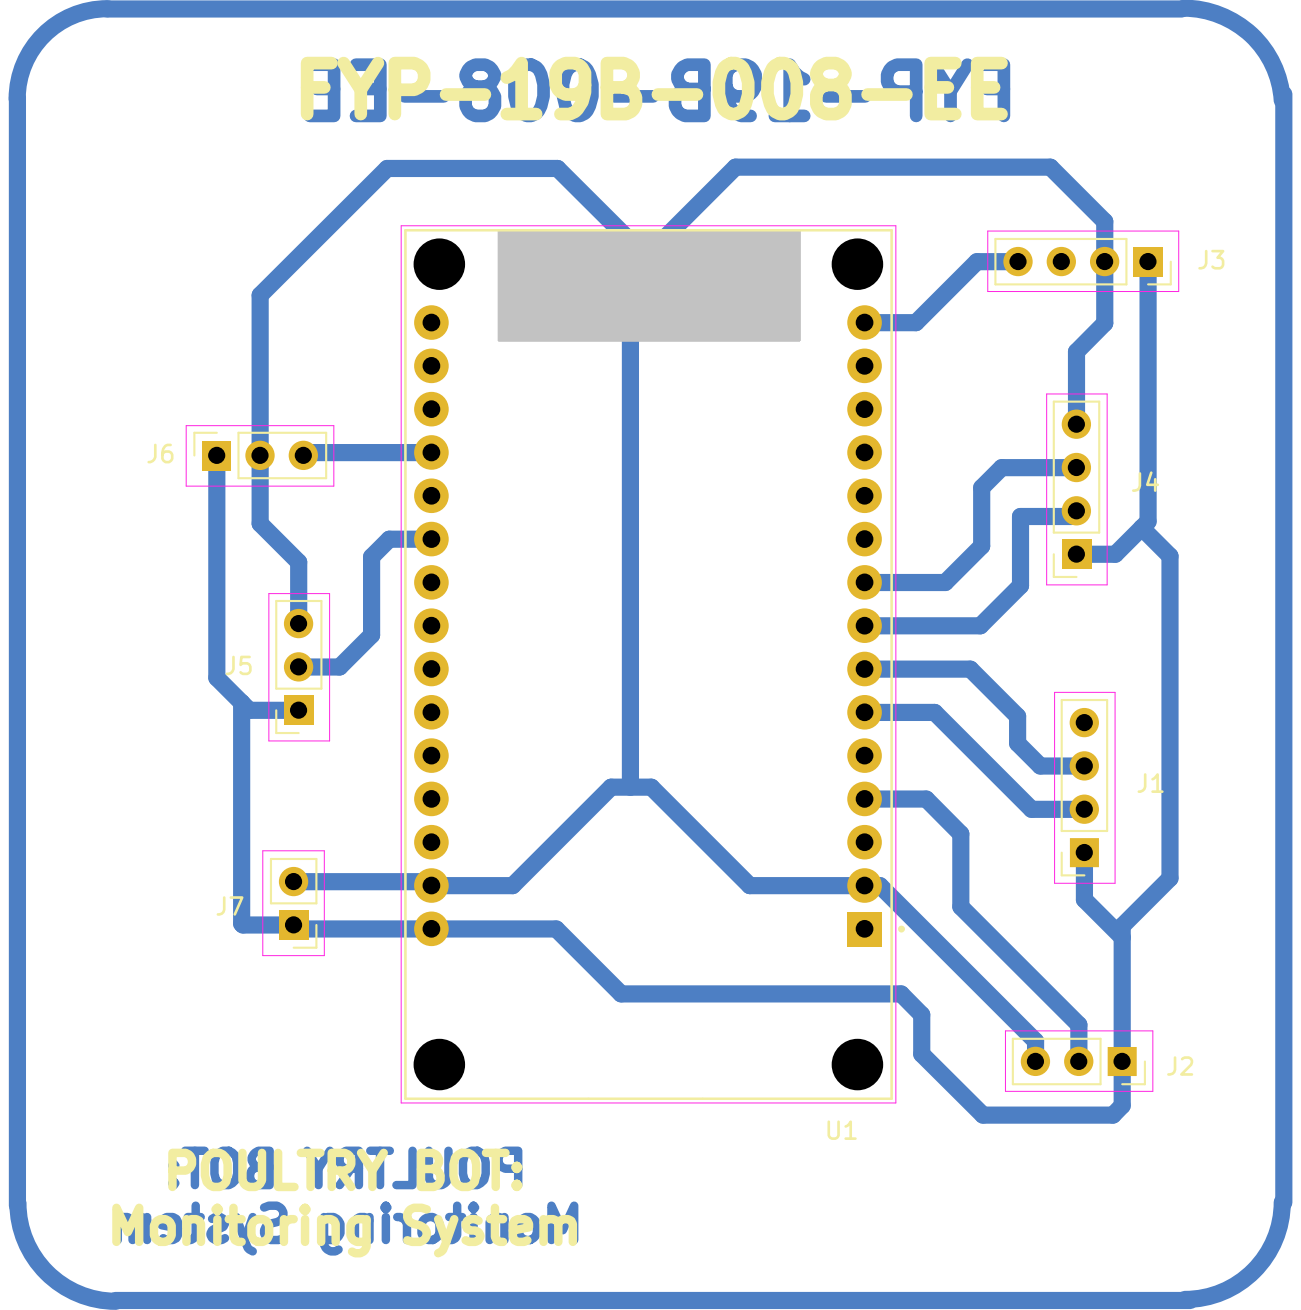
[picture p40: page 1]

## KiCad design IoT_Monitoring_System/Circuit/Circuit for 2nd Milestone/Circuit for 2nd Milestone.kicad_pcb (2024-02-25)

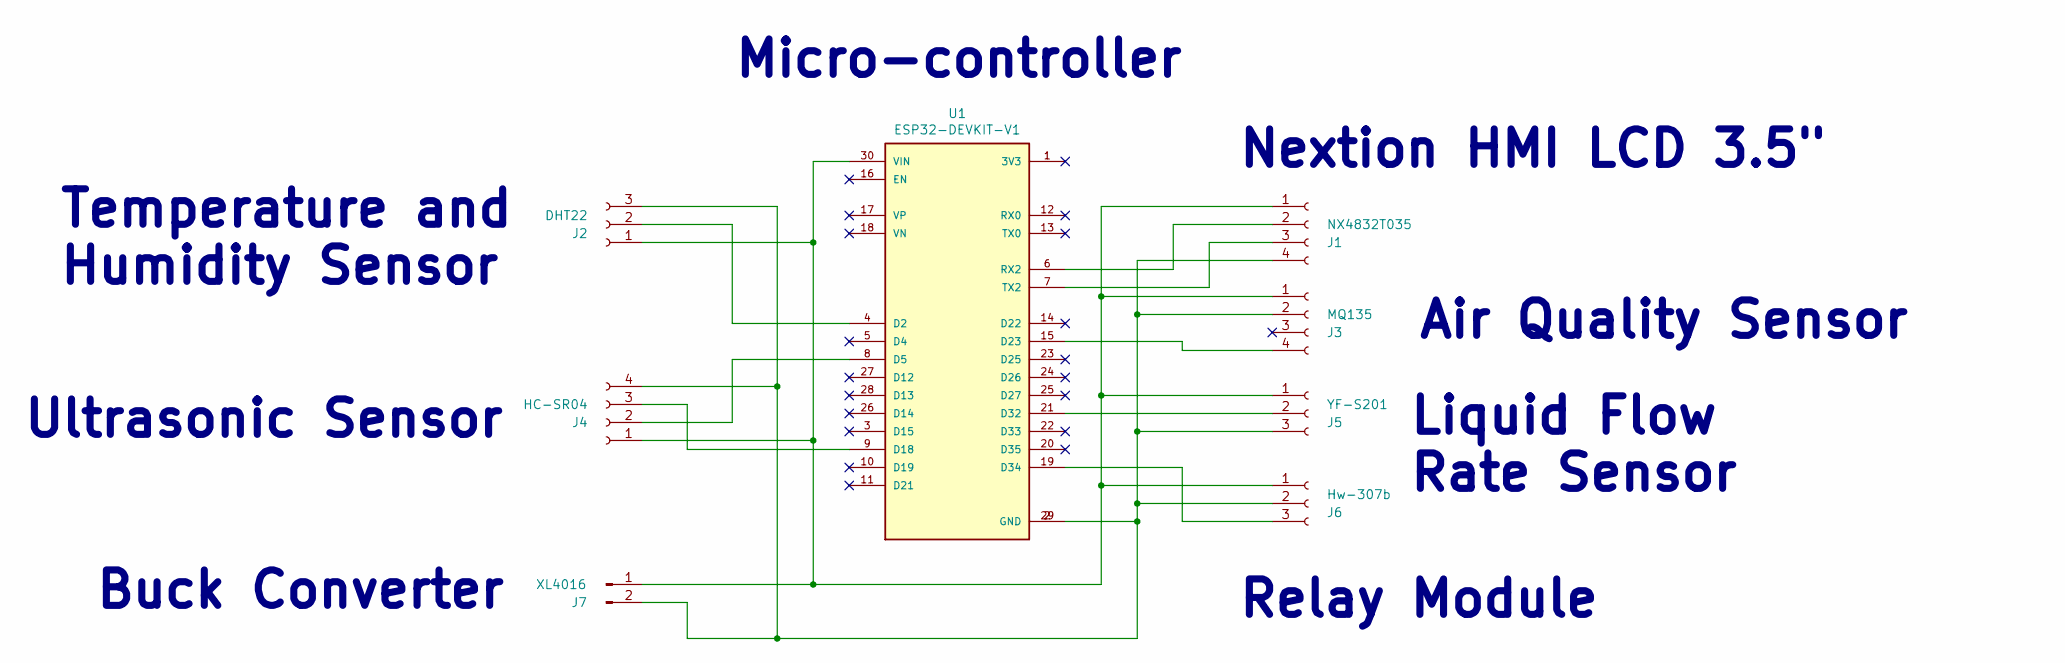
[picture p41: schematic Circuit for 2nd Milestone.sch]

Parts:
J1: NX4832T035; PinSocket_1x04_P2.54mm_Vertical
J2: DHT22; PinSocket_1x03_P2.54mm_Vertical
J3: MQ135; PinSocket_1x04_P2.54mm_Vertical
J4: HC-SR04; PinSocket_1x04_P2.54mm_Vertical
J5: YF-S201; PinSocket_1x03_P2.54mm_Vertical
J6: Hw-307b; PinSocket_1x03_P2.54mm_Vertical
J7: XL4016; PinHeader_1x02_P2.54mm_Vertical
U1: ESP32-DEVKIT-V1; MODULE_ESP32_DEVKIT_V1; PARTREV N/A

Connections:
5V: J1.1, J2.1, J3.1, J4.1, J5.1, J6.1, J7.1, U1.30 (VIN)
DHT22: J2.2, U1.4 (D2)
Echo: J4.3, U1.9 (D18)
GND: J1.4, J2.3, J3.2, J4.4, J5.3, J6.2, J7.2, U1.2 (GND), U1.29 (GND)
MQ135: J3.4, U1.15 (D23)
RX: J1.3, U1.7 (TX2)
Relay: J6.3, U1.19 (D34)
TX: J1.2, U1.6 (RX2)
Trigger: J4.2, U1.8 (D5)
YF-S201: J5.2, U1.21 (D32)

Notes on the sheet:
Ultrasonic Sensor
Micro-controller
Relay Module
Liquid Flow Rate Sensor
Air Quality Sensor
Temperature and Humidity Sensor
Nextion HMI LCD 3.5"
Buck Converter

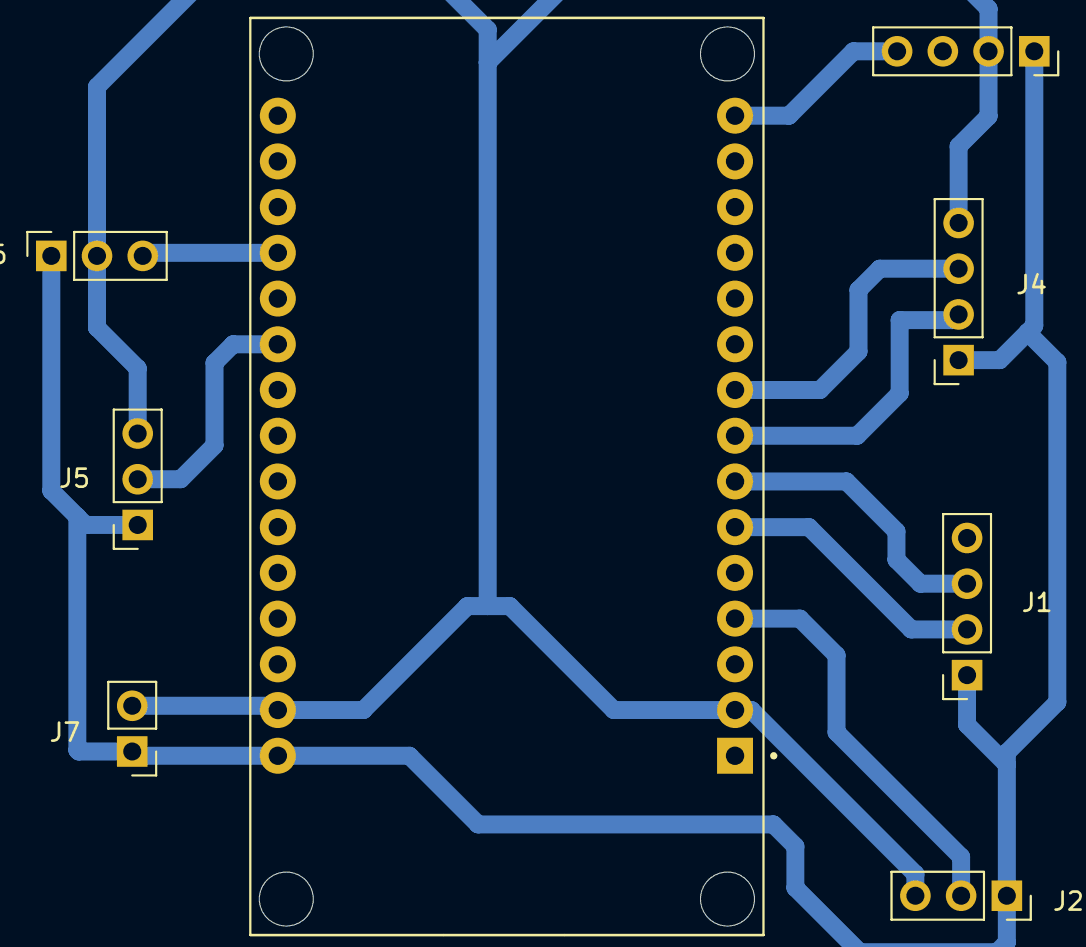
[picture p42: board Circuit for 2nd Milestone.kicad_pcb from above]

Board: 2 copper layers, 8 parts (0 on the bottom side), 10 nets.

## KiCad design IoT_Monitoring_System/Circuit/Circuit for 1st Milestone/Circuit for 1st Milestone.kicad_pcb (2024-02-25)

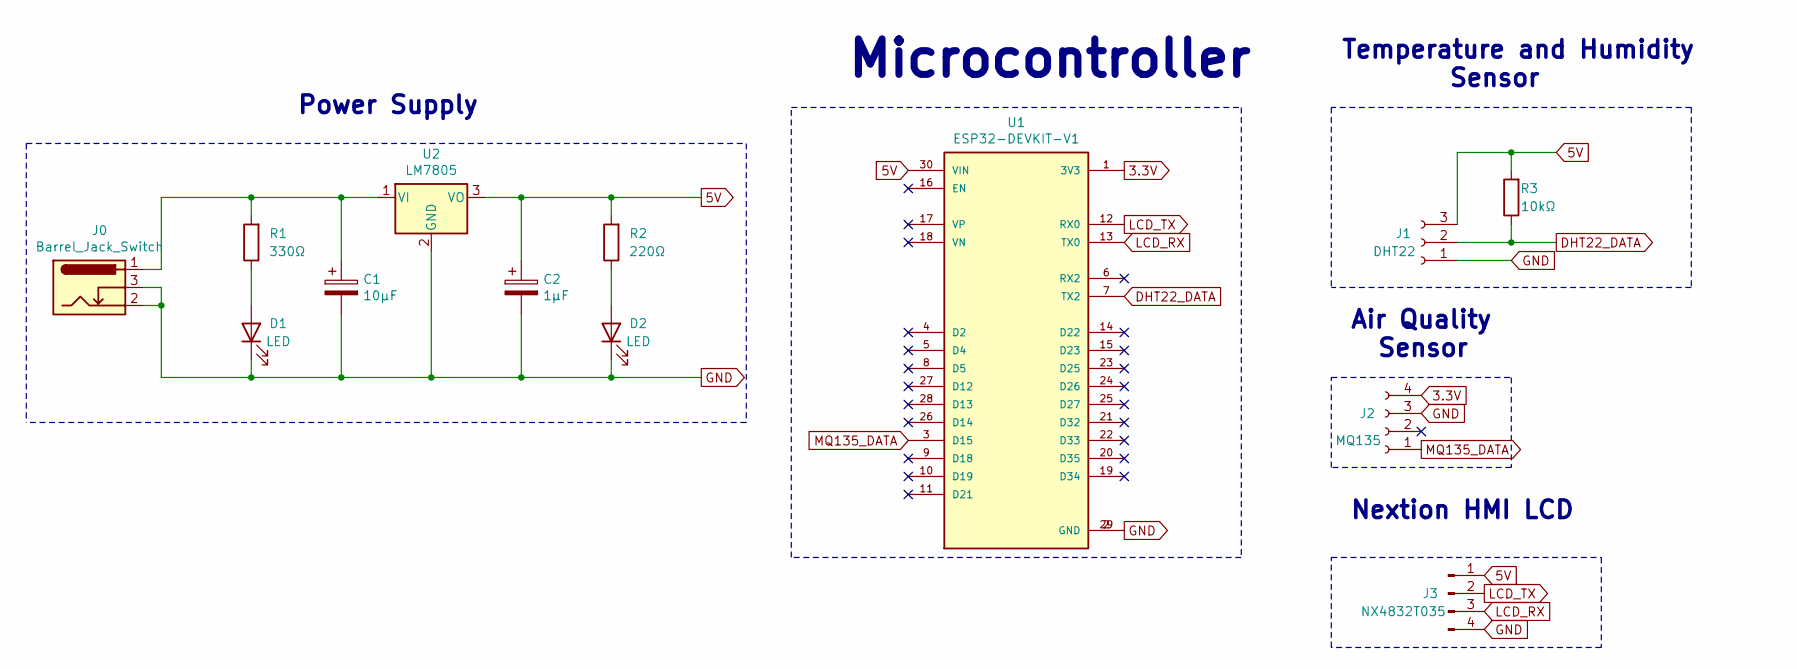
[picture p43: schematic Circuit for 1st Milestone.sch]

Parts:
C1: 10μF; CP_Radial_D6.3mm_P2.50mm
C2: 1μF; CP_Radial_D6.3mm_P2.50mm
D1, D2: LED; LED_D5.0mm_Clear
J0: Barrel_Jack_Switch; BarrelJack_Horizontal
J1: DHT22; PinSocket_1x03_P2.54mm_Vertical
J2: MQ135; PinSocket_1x04_P2.54mm_Vertical
J3: NX4832T035; PinHeader_1x04_P2.54mm_Vertical
R1: 330Ω; R_Axial_DIN0207_L6.3mm_D2.5mm_P10.16mm_Horizontal
R2: 220Ω; R_Axial_DIN0207_L6.3mm_D2.5mm_P10.16mm_Horizontal
R3: 10kΩ; R_Axial_DIN0207_L6.3mm_D2.5mm_P10.16mm_Horizontal
U1: ESP32-DEVKIT-V1; MODULE_ESP32_DEVKIT_V1; PARTREV N/A
U2: LM7805; TO-220-3_Vertical

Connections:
3.3V: J2.4, U1.1 (3V3)
5V: C2.1, J1.3, J3.1, R2.2, R3.2, U1.30 (VIN), U2.3 (VO)
DHT22_DATA: J1.2, R3.1, U1.7 (TX2)
GND: C1.2, C2.2, D1.1 (K), D2.1 (K), J0.2, J0.3, J1.1, J2.3, J3.4, U1.2 (GND), U1.29 (GND), U2.2 (GND)
LCD_RX: J3.3, U1.13 (TX0)
LCD_TX: J3.2, U1.12 (RX0)
MQ135_DATA: J2.1, U1.3 (D15)
unnamed: C1.1, J0.1, R1.2, U2.1 (VI)
unnamed: D1.2 (A), R1.1
unnamed: D2.2 (A), R2.1

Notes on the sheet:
Temperature and Humidity Sensor
Air Quality Sensor
Nextion HMI LCD
Power Supply
Microcontroller

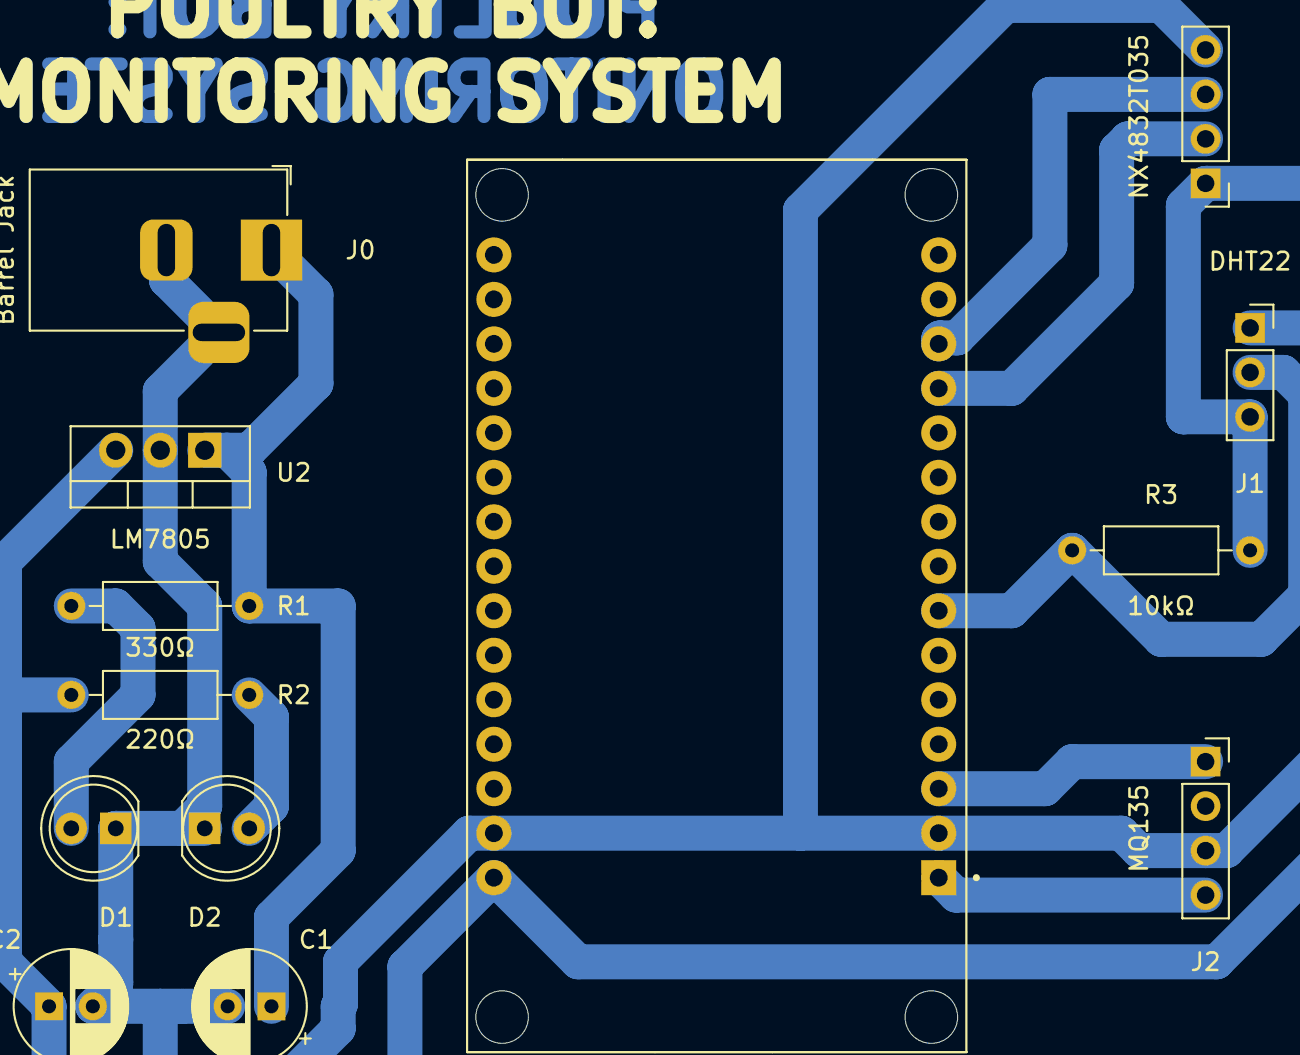
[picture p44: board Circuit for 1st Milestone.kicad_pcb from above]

Board: 2 copper layers, 13 parts (0 on the bottom side), 10 nets.

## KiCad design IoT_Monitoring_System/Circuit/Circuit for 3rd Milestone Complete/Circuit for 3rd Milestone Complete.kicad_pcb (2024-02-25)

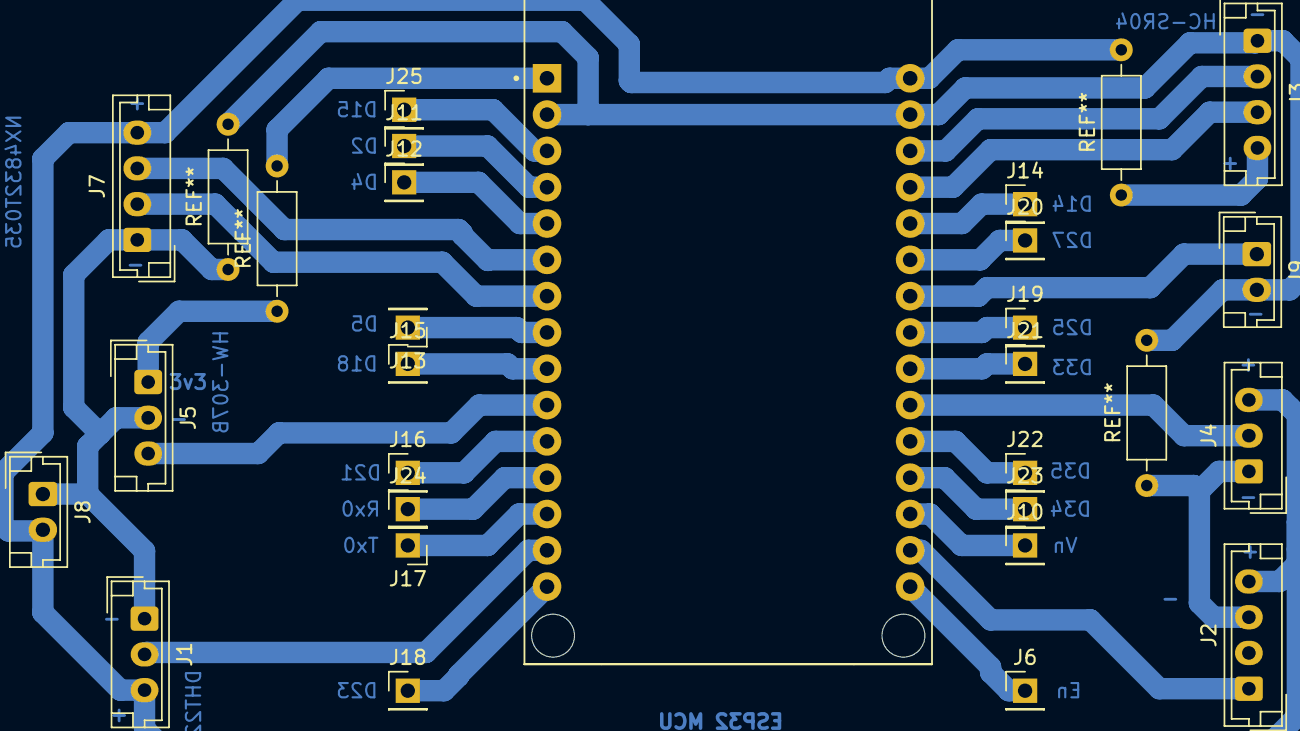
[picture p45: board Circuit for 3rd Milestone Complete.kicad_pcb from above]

Board: 2 copper layers, 26 parts (0 on the bottom side), 29 nets.

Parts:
J1: DHT22; JST_EH_B3B-EH-A_1x03_P2.50mm_Vertical
J2: MQ135; JST_EH_B4B-EH-A_1x04_P2.50mm_Vertical
J3: HC-SR04; JST_EH_B4B-EH-A_1x04_P2.50mm_Vertical
J4: YF-S201; JST_EH_B3B-EH-A_1x03_P2.50mm_Vertical
J5: HW-307B; JST_EH_B3B-EH-A_1x03_P2.50mm_Vertical
J6: En; PinHeader_1x01_P2.54mm_Vertical
J7: NX4832T035; JST_EH_B4B-EH-A_1x04_P2.50mm_Vertical
J8: XL4016; JST_EH_B2B-EH-A_1x02_P2.50mm_Vertical
J9: Litter Raking; JST_EH_B2B-EH-A_1x02_P2.50mm_Vertical
J10: Vn; PinHeader_1x01_P2.54mm_Vertical
J11: D2; PinHeader_1x01_P2.54mm_Vertical
J12: D4; PinHeader_1x01_P2.54mm_Vertical
J13: D5; PinHeader_1x01_P2.54mm_Vertical
J14: D14; PinHeader_1x01_P2.54mm_Vertical
J15: D18; PinHeader_1x01_P2.54mm_Vertical
J16: D21; PinHeader_1x01_P2.54mm_Vertical
J17: Tx0; PinHeader_1x01_P2.54mm_Vertical
J18: D23; PinHeader_1x01_P2.54mm_Vertical
J19: D25; PinHeader_1x01_P2.54mm_Vertical
J20: D27; PinHeader_1x01_P2.54mm_Vertical
J21: D33; PinHeader_1x01_P2.54mm_Vertical
J22: D35; PinHeader_1x01_P2.54mm_Vertical
J23: D34; PinHeader_1x01_P2.54mm_Vertical
J24: Rx0; PinHeader_1x01_P2.54mm_Vertical
J25: D15; PinHeader_1x01_P2.54mm_Vertical
U1: ESP32 MCU; MODULE_ESP32_DEVKIT_V1

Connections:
unnamed: J2.1, U1.17 (VP)
unnamed: J1.1, J2.3, J3.1, J4.1, J5.2, J7.1, J8.1, J9.2, U1.2 (GND), U1.29 (GND)
unnamed: J1.3, J2.4, J3.4, J4.3, J7.4, J8.2, U1.30 (VIN)
unnamed: J4.2, U1.21 (D32)
unnamed: J5.1, U1.1 (3V3)
unnamed: J25.1, U1.3 (D15)
unnamed: J11.1, U1.4 (D2)
unnamed: J12.1, U1.5 (D4)
unnamed: J7.3, U1.6 (RX2)
unnamed: J7.2, U1.7 (TX2)
unnamed: J13.1, U1.8 (D5)
unnamed: J15.1, U1.9 (D18)
unnamed: J5.3, U1.10 (D19)
unnamed: J16.1, U1.11 (D21)
unnamed: J24.1, U1.12 (RX0)
unnamed: J17.1, U1.13 (TX0)
unnamed: J1.2, U1.14 (D22)
unnamed: J18.1, U1.15 (D23)
unnamed: J6.1, U1.16 (EN)
unnamed: J10.1, U1.18 (VN)
unnamed: J23.1, U1.19 (D34)
unnamed: J22.1, U1.20 (D35)
unnamed: J21.1, U1.22 (D33)
unnamed: J19.1, U1.23 (D25)
unnamed: J9.1, U1.24 (D26)
unnamed: J20.1, U1.25 (D27)
unnamed: J14.1, U1.26 (D14)
unnamed: J3.3, U1.27 (D12)
unnamed: J3.2, U1.28 (D13)

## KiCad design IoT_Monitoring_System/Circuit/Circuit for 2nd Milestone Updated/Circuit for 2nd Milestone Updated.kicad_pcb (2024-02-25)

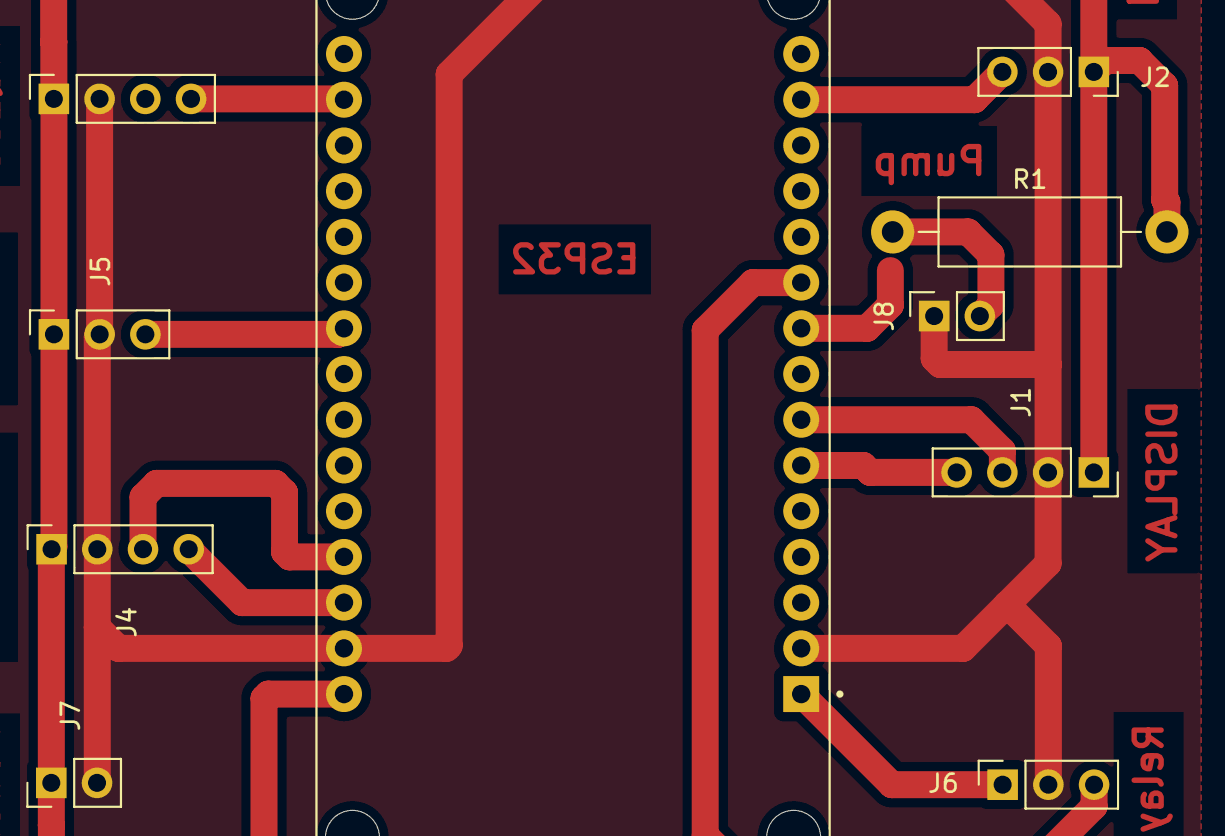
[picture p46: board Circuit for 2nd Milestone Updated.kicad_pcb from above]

Board: 2 copper layers, 10 parts (0 on the bottom side), 7 nets.

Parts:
J1: NX4832T035; PinSocket_1x04_P2.54mm_Vertical
J2: DHT22; PinSocket_1x03_P2.54mm_Vertical
J3: MQ135; PinSocket_1x04_P2.54mm_Vertical
J4: HC-SR04; PinSocket_1x04_P2.54mm_Vertical
J5: YF-S201; PinSocket_1x03_P2.54mm_Vertical
J6: Hw-307b; PinSocket_1x03_P2.54mm_Vertical
J7: XL4016; PinHeader_1x02_P2.54mm_Vertical
J8: Pump Input; PinSocket_1x02_P2.54mm_Vertical
R1: R; R_Axial_DIN0411_L9.9mm_D3.6mm_P15.24mm_Horizontal
U1: ESP32-DEVKIT-V1; MODULE_ESP32_DEVKIT_V1

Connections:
unnamed: J1.1, J2.1, J3.1, J4.1, J5.1, J7.1, R1.2
unnamed: J1.2, J2.2, J3.2, J4.2, J5.2, J6.2, J7.2, J8.1
unnamed: U1.2 (GND), U1.29 (GND)
unnamed: J3.4, U1.17 (VP)
unnamed: J6.1, U1.1 (3V3)
unnamed: J6.3, U1.10 (D19)
unnamed: J8.2, R1.1

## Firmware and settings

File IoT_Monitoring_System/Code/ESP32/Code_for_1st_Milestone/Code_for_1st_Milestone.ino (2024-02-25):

#include <WiFi.h>
#include <WiFiClient.h>
#include <BlynkSimpleEsp32.h>


#define BLYNK_TEMPLATE_ID "TMPLqo4MJG8x"
#define BLYNK_DEVICE_NAME "IoT"
#define BLYNK_AUTH_TOKEN "gkp3KEPrshlwgZ00bzexG33Jd64ayy_U"

char ssid[]= "B-94";
char pass[]= "d24b687c";


#include "DHT.h"
#include "MQUnifiedsensor.h"// MQ135 Enable
// #include <SoftwareSerial.h>
#include <HardwareSerial.h>

#ifndef ESP32
#pragma message(THIS EXAMPLE IS FOR ESP32 ONLY!)
#error Select ESP32 board.
#endif

//Definitions
#define dhtPin 17
#define DHTTYPE DHT22
#define mqPin 36
#define lcd_tx 1 //tx0
#define lcd_rx 3 //rx0
#define litter 16 //rx2
#define pump 15 //d15
#define valve 02 //d2

#define board ("ESP-32")          // Development Board
#define Voltage_Resolution 3.3    // VCC
#define pin 15                    // Analog Input 0 of ESP32
#define type "MQ-135"             // MQ135
#define ADC_Bit_Resolution 12     // For ESP32
#define RatioMQ135CleanAir 3.6    // RS / R0 = 3.6 ppm

MQUnifiedsensor MQ135(board, Voltage_Resolution, ADC_Bit_Resolution, pin, type);
DHT dht(dhtPin, DHTTYPE);

float NH4 = 3;
int h, t, nh;
unsigned long prevTime = 0;

void setup(void){
  Serial.begin(9600);
  // mySerial.begin(115200);

//Set math model to calculate the PPM concentration and the value of constants
  MQ135.setRegressionMethod(1); //_PPM =  a*ratio^b
  MQ135.setA(110.47); MQ135.setB(-2.862); // Configure the equation to to calculate C02 concentration
  dht.begin();
    /*
    Exponential regression:
  GAS      | a      | b
  CO       | 605.18 | -3.937  
  Alcohol  | 77.255 | -3.18 
  CO2      | 110.47 | -2.862
  Toluen   | 44.947 | -3.445
  NH4      | 102.2  | -2.473
  Aceton   | 34.668 | -3.369
  */
  
  MQ135.init(); 
  Serial.print("Calibrating please wait.");
  float calcR0 = 0;
  for(int i = 1; i<=10; i ++)
  {
    MQ135.update(); // Update data, the arduino will read the voltage from the analog pin
    calcR0 += MQ135.calibrate(RatioMQ135CleanAir);
    Serial.print(".");
  }
  MQ135.setR0(calcR0/10);
  // Serial.println("  done!.");
  
  if(isinf(calcR0)) {Serial.println("Warning: Conection issue, R0 is infinite (Open circuit detected) please check your wiring and supply"); while(1);}
  if(calcR0 == 0){Serial.println("Warning: Conection issue found, R0 is zero (Analog pin shorts to ground) please check your wiring and supply"); while(1);}
  MQ135.serialDebug(true);
  MQ135.setA(102.2); MQ135.setB(-2.473); // Configure the equation to to calculate NH4 concentration

  Blynk.begin(BLYNK_AUTH_TOKEN, ssid, pass, "blynk.cloud", 80);
  Blynk.run();

  delay(1000);
}

void loop(void){
  unsigned long currentTime = millis();
  if(currentTime-prevTime >= 3000){
      prevTime = currentTime - millis();
      if(NH4 == 3){
        NH4 = 4;
      }
      else if(NH4 == 4){
        NH4 = 3;
      }
  }
  MQ135.update(); // Update data, the arduino will read the voltage from the analog pin
  MQ135.readSensor(); // Sensor will read PPM concentration using the model, a and b values set previously or from the setup
  NH4 = MQ135.ppmprint(1);
  delay(150);
  h = dht.readHumidity();
  t = dht.readTemperature();
  Blynk.virtualWrite(V0, t);
  Blynk.virtualWrite(V1, h);
  Blynk.virtualWrite(V2,nh);
  //temprature page
Serial.print("n1.val=");
  Serial.print(t);
Serial.write(0xff);
Serial.write(0xff);
Serial.write(0xff);
  // float bar = 100*(t/125+4);
  Serial.print("j1.val=");
  Serial.print(t);
Serial.write(0xff);
Serial.write(0xff);
Serial.write(0xff);
//humidity page
Serial.print("n2.val=");
  Serial.print(h);
Serial.write(0xff);
Serial.write(0xff);
Serial.write(0xff);
Serial.print("j2.val=");
  Serial.print(h);
Serial.write(0xff);
Serial.write(0xff);
Serial.write(0xff);
//Ammonia Page
Serial.print("n3.val=");
nh=NH4;
  Serial.print(nh);
Serial.write(0xff);
Serial.write(0xff);
Serial.write(0xff);


}

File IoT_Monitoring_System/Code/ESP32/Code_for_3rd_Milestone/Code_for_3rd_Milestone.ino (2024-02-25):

#include <Arduino.h>
#include "DHT.h"
#include "EasyNextionLibrary.h"
#include "WiFi.h"
#include "ThingSpeak.h" 
#include <HTTPClient.h>
#include <FlowSensor.h>
#include <NewPing.h>

// put pin definitions here
const int dhtPin = 22;
const int mqPin = 36; //vp
const int pumpPin = 19;
const int pumpInput = 18;
const int flowSensorPin = 33;
const int trigger = 12;
const int echo = 13;
// const int arduinoSend = 1;
const int litter = 26;

// Constants
#define WIFI_TIMEOUT_MS 2000
// #define WIFI_NETWORK "EVO-Charji-7404"
// #define WIFI_PASSWORD "BSJ5vr5M"
#define WIFI_NETWORK "B-94"
#define WIFI_PASSWORD "d24b687c"
#define CHANNELID 2047728 //2184577
#define APIKEY "PKNGA4A9TABT1FN2" //"33WFVMB4KNV4QM8Z"
#define MAX_DISTANCE 60 //cm

// Struct declarations
DHT dht(dhtPin, DHT22);
EasyNex myDisplay(Serial2); 
WiFiClient client;
FlowSensor Sensor(YFS201, flowSensorPin);
NewPing sonar(trigger, echo, MAX_DISTANCE); // NewPing setup of pins and maximum distance.
HardwareSerial SerialPort(1);


//variables under monitoring
float humidity, temperature, flowRate, distance;
int intTemp;
int pumpStatus = 1;
int angle;
int mqVoltage, ammoniaPPB, ammoniaPPM;
unsigned long lastPrintTime = 1000;
unsigned long lastDisplayUpdate = 1000;
unsigned long lastUpdateTemp = 1000;
unsigned long lastUpdateHumidity = 2000;
unsigned long lastUpdateAmmonia= 3000;
unsigned long lastUpdateLiquid= 4000;
unsigned long lastUpdateFlow= 5000;
unsigned long lastUpdateBattery =6000;
unsigned long lastUpdateWifi =60000;
unsigned long timebefore = 0; // Same type as millis() for pump reading
String stringFromNextion;

// put function declarations here:
void count()
{
  Sensor.count();
}

void connectWifi(){
  Serial.println("Connecting to Wifi");
  WiFi.mode(WIFI_STA);
  WiFi.begin(WIFI_NETWORK, WIFI_PASSWORD);
  unsigned long startAttemptTime = millis();
  
  while(WiFi.status()!= WL_CONNECTED && (millis()-startAttemptTime) <= WIFI_TIMEOUT_MS){
    Serial.print(".");
    delay(200);
  }

  if(WiFi.status() != WL_CONNECTED){
    Serial.println("Failed to connect wifi");
  }
  else{
    Serial.println("Connection Successfull");
    Serial.println(WiFi.localIP());
  }
}

//Main Functions
void setup() {
  delay(1000);
  SerialPort.begin (115200, SERIAL_8N1, 4, 2);
  Serial.begin(115200);
  Serial2.begin(9600);
  Serial1.begin(115200);
  pinMode(pumpPin, OUTPUT);
  pinMode(litter, OUTPUT);
  connectWifi();
  Sensor.begin(count);
  lastPrintTime = millis();
  ThingSpeak.begin(client);
  myDisplay.writeNum("n0.val", 0);
  delay(3000);
}

void loop() {
  
  //pump using display
  String num = myDisplay.readStr("t6.txt");
      if (num == "Pump is ON") {
      Serial.println("Turn PUMP ON");
      digitalWrite(pumpPin, LOW);
    }
    else if (num == "Pump is OFF"){
      Serial.println("Turn PUMP OFF");
      digitalWrite(pumpPin, HIGH);
    }
  
  //Liquid Flow rate sensing
  if (millis() - timebefore >= 1000)
  {
    Sensor.read();
    Serial.print("Flow rate (L/minute) : ");
    flowRate = Sensor.getFlowRate_m();
    Serial.println(flowRate);
    timebefore = millis();
    delay(50);                     // Wait 50ms between pings (about 20 pings/sec). 29ms should be the shortest delay between pings.
    Serial.print("Ping: ");
    distance = sonar.ping_cm();
    Serial.print(distance); // Send ping, get distance in cm and print result (0 = outside set distance range)
    Serial.println("cm");
  }

  //updating display after reading latest sensor values
  if(millis()-lastDisplayUpdate >= 2500){
    humidity = dht.readHumidity();
    temperature = dht.readTemperature();

    //temperature to angle conversrion
    angle = ((temperature - (-40)) * (180 - 0) / (80 - (-40))) + 0; 
    mqVoltage = analogRead(mqPin);
    ammoniaPPB = map(mqVoltage,0, 4095, 0, 500);
    ammoniaPPM = ammoniaPPB/10;
    Serial1.write(ammoniaPPM);

    Serial.println("===========================");
    Serial.print("Humidity = ");
    Serial.println(humidity);
    Serial.print("temp = ");
    Serial.println(temperature);
    Serial.print("MQ Voltage = ");
    Serial.println(mqVoltage);
    Serial.println("===========================");

    //Display values update
    Serial.println("Updating Display");
    myDisplay.writeNum("n1.val", temperature);
    myDisplay.writeNum("z1.val", angle);    //temperature guage angle
    myDisplay.writeNum("n2.val", humidity);
    myDisplay.writeNum("j2.val", humidity); //progress bar
    myDisplay.writeNum("n3.val", ammoniaPPM);

    //distance query here
    if(distance >= 33){
      myDisplay.writeStr("t4.txt", "EMPTY");
    }
    if(distance >= 24 && distance<= 33){
      myDisplay.writeStr("t4.txt", "LOW");
    }
    if(distance >= 12 && distance <= 24){
      myDisplay.writeStr("t4.txt", "MEDIUM");
    }
    if(distance >= 3 && distance <= 12){
      myDisplay.writeStr("t4.txt", "HIGH");
    }
    if(distance >= 0 && distance <= 3){
      myDisplay.writeStr("t4.txt", "OVERFLOW");
    }
    myDisplay.writeNum("x5.val", flowRate/100);
    myDisplay.writeNum("h5.val", flowRate/100);

    //litter raking
    if(ammoniaPPM >= 25){
      digitalWrite(litter, HIGH);
      myDisplay.writeStr("g7.txt", "Litter Raking is ON" );
      myDisplay.writeNum("g7.bco", 2016 );
      myDisplay.writeNum("g7.pco", 65535 );
      myDisplay.writeNum("g7.dir", 0 );
    }
    else{
      digitalWrite(litter, LOW);
      myDisplay.writeStr("g7.txt", "Litter Raking is OFF" );
      myDisplay.writeNum("g7.bco", 63488 );
      myDisplay.writeNum("g7.pco", 65535 );
      myDisplay.writeNum("g7.dir", 1 );
    }

    lastDisplayUpdate = millis();
  }

  //dashboard update
  if(millis()-lastUpdateAmmonia >= 20000){
    Serial.println("Updating Dashboard");
    ThingSpeak.setField(1, temperature);
    ThingSpeak.setField(2, humidity);
    ThingSpeak.setField(3, ammoniaPPM);
    ThingSpeak.setField(4, distance);
    ThingSpeak.setField(5, flowRate);
    ThingSpeak.writeFields(CHANNELID, APIKEY);
    lastUpdateAmmonia = millis();
  }
}

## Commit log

2023-11-26 Added Bot Structure
    [Base.dwg, Base_Modified.dwg, Complete.dwg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]
2023-11-26 Changed Robot Structure Path
    [Base.dwg, Base_Modified.dwg, Complete.dwg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]
2023-11-27 inserted Book
2024-02-25 Add firmware
    Firmware of Monitoring Controller and ESP Camera
2024-02-25 Add circuit files for 1st, 2nd and 3rd milestones
    [Circuit for 1st Milestone Modified.sch, Circuit for 1st Milestone.kicad_pcb, Circuit for 1st Milestone.sch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]
2024-02-25 Remove unwanted files
    [Circuit for 1st Milestone Modified.sch, Circuit for 1st Milestone.kicad_pcb, Circuit for 1st Milestone.sch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]
2024-02-25 Add circuit files
    [Circuit for 1st Milestone Modified.sch, Circuit for 1st Milestone.kicad_pcb, Circuit for 1st Milestone.sch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]
